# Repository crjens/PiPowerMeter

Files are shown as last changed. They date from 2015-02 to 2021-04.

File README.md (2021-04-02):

PiPowerMeter
=====

PiPowerMeter is an energy usage monitor based on the Cirrus Logic CS5463/5490 energy IC's (http://www.cirrus.com/en/products/pro/detail/P1092.html) and a Raspberry Pi.  It consists of two custom designed stacking pcb's.  The control board houses the power supply, energy IC, voltage sensors and supporting electronics.  The input board houses 16 multiplexed current input channels that allow monitoring up to 16 different circuits via standard clamp-on ct's.  A single control board supports up to 8 stacked input boards for a total monitoring capacity of up to 128 circuits.
The system is controlled by a nodejs based program running on the Raspberry Pi and includes a self contained web based monitoring portal.  Energy data are stored locally on the Raspberry Pi in a sqlite database making the system 100% stand-alone with no requirement for additional hardware or external servers.

Features
--------
 - 100% stand alone system with no reliance on external hardware or servers
 - Ability to monitor up to 128 circuits via round-robin sampling
 - Uses simple off the shelf clamp-on current sensors
 - Highly accurate measurement of voltage, current, power usage and power factor based on CS5463/CS5490 energy IC
 - Raspberry Pi based control system
   * All data stored locally in sqlite database
   * Web based monitoring portal for viewing energy usage and configuration
   * Ability to receive text alerts for overloads or other events.

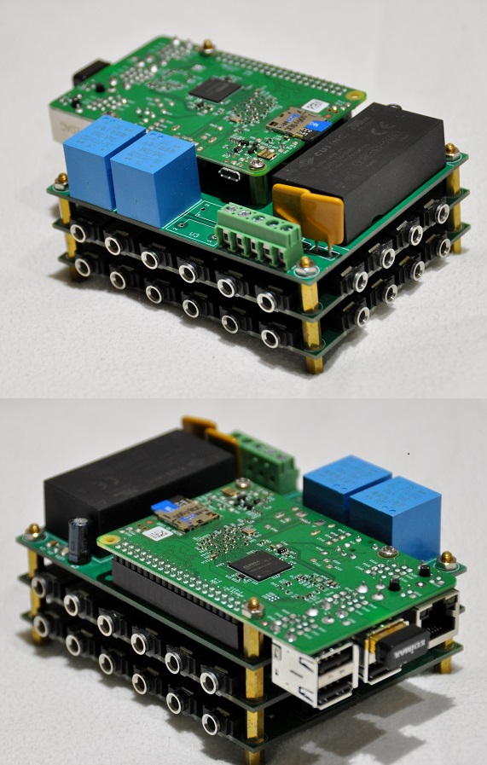
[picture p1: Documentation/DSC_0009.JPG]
hardware
 

Screenshots
-----------
- [Main](https://raw.githubusercontent.com/crjens/PiPowerMeter/master/Documentation/main.png)
- [Daily](https://raw.githubusercontent.com/crjens/PiPowerMeter/master/Documentation/graph.png)
- [Instantaneous](https://raw.githubusercontent.com/crjens/PiPowerMeter/master/Documentation/instant.png)
- [Readings](https://raw.githubusercontent.com/crjens/PiPowerMeter/master/Documentation/readings.png)
- [Configuration](https://raw.githubusercontent.com/crjens/PiPowerMeter/master/Documentation/config.png)

Additional Images
-----------------
- [Installed System](https://raw.githubusercontent.com/crjens/PiPowerMeter/master/Documentation/DSC_0077.JPG)
- [Installed System 2](https://raw.githubusercontent.com/crjens/PiPowerMeter/master/Documentation/DSC_0078.JPG)
- [Sensors](https://raw.githubusercontent.com/crjens/PiPowerMeter/master/Documentation/DSC_0002.JPG)
- [Boards](https://raw.githubusercontent.com/crjens/PiPowerMeter/master/Documentation/DSC_0012.JPG)

Hardware Installation
---------------------
1. The Raspberry Pi mounts directly to the 40-pin header on the control board and is powered from the control board's universal power supply.  Do not attempt to power the Raspberry Pi via its micro usb port or it may be damaged.
2. The control board requires a direct connection to the AC power source that is being monitored.  This AC connection provides both the voltage reference for the energy calculations as well as the power source for the Raspberry Pi and supporting electronics.  The AC power source is connected via 5 pin terminal connector shown [here](https://raw.githubusercontent.com/crjens/PiPowerMeter/master/Documentation/ACIn.jpg) and supports 100-240VAC and 50/60Hz.  

	- For US 120/240V split phase connect Ground, Neutral, AC1 and AC2.
	- For 240V single phase connect Ground, Neutral and AC1.
	- For 3 phase connect Ground, Neutral, AC1, AC2 and AC3.
3. Current sensors are connected to the input board via standard 3.5mm (1/8") audio plugs.  They must be current-type sensors without built-in sense resistors and must produce a full scale output of less than 50mA.  YHDC produces a full line of split-core current sensors that are easy to use, inexpensive and readily available [online](https://www.ebay.com/sch/i.html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). Popular models include:
	- [YHDC-006 (20A)](http://en.yhdc.com/product1311.html?productId=612)
	- [YHDC-013-000 (100A)](http://en.yhdc.com/product1311.html?productId=401)
	- [YHDC-019 (200A)](http://en.yhdc.com/product1311.html?productId=380)
4. Connect the current sensors so that the current polarity reads correctly, (+) for circuits that consume energy and (-) for circuits that produce energy.  Connecting a sensor backwards will not harm anything so if you're not sure which way it should face just pick a direction and then reverse it if the readings are opposite of what you expect. 
	- Current sensors measure the sum of the current passing through them so they should normally be connected to a single conductor.  If connected to a multi-conductor cable, the current flowing in the line and neutral conductors will cancel each other and the sensor will read zero current.
	- YHDC sensors connected to line conductors should be oriented so that the printing on the face of the sensor faces toward the source (there's also an arrow on most sensors that should point toward the source).  If the sensor is connected to the neutral the direction should be reversed.  
5. Once the sensors are installed you'll need to configure the software to enable them.  This is done in the configuration page by adding a new circuit for each sensor and setting the sensor type, board, circuit and voltage reference.
	- There are several preconfigured types for common YHDC sensors and you can add additional types under the configuration tab.  When creating new sensor types set the scale value to 0.05 * the turns ratio of the sensor.  (YHDC SCT-013 has a turns ratio of 2000:1 so scale factor is 0.05*2000=100)
	- Board should be set to the id of the current board that the sensor is plugged into (0-7).
	- Channel should be set to the id that the sensor is plugged into (0-15).
	- Set Voltage to the voltage reference for the circuit.  If you aren't sure you can take a look at the current and voltage waveforms on the circuit page and experiment until you find the voltage reference that most closely matches the phase of the current waveform.
	- SampleTime sets the amount of time in seconds that the input current and voltage are sampled for each calculation.  Decreasing the SampleTime allows faster sampling but may adversly affect the accuracy of the calculations.  Valid values are between 0.05 and 60 seconds.  
	- Incorrect software settings won't cause any damage so you can experiment until you get them right.

Software Installation
---------------------
1. Any of the full size Raspberry Pi models with the 40 pin header are supported including: V1 A+, V1 B+, V2, V3 B, V3 B+ and V4 B.  The additional memory and computing power of the V2/V3/V4 models is recommended.
2. Start with latest Raspbian image from https://www.raspberrypi.org/software/operating-systems/
	1. (verified with Raspberry PI OS Lite 2021-03-04)
	2. It's recommended that you use the Lite version because it's smaller and installs faster but you can use either.
3. login to Pi with Putty or other ssh client
	1. the latest versions of Raspbian have ssh disabled.  You can enable ssh via raspi-config or just create an empty file named 'ssh' in the boot partition of the sd card.
4. Install the PiPowerMeter software by running the following command (you must install with root privileges such as the built-in pi account):
	1. wget -O - https://raw.githubusercontent.com/crjens/PiPowerMeter/master/setup.sh | bash
5. run 'sudo raspi-config' 
	1. set locale and timezone under Localisation options
	2. expand filesystem under Advanced options
	3. change user password (optional)
	4. reboot when prompted after exiting raspi-config
6. Open your browser to http://<Your Raspberry Pi's IP Address>:3000

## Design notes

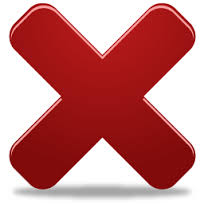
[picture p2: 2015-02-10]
public/images/delete.jpg

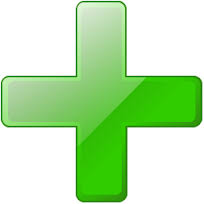
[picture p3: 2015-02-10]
public/images/add.jpg

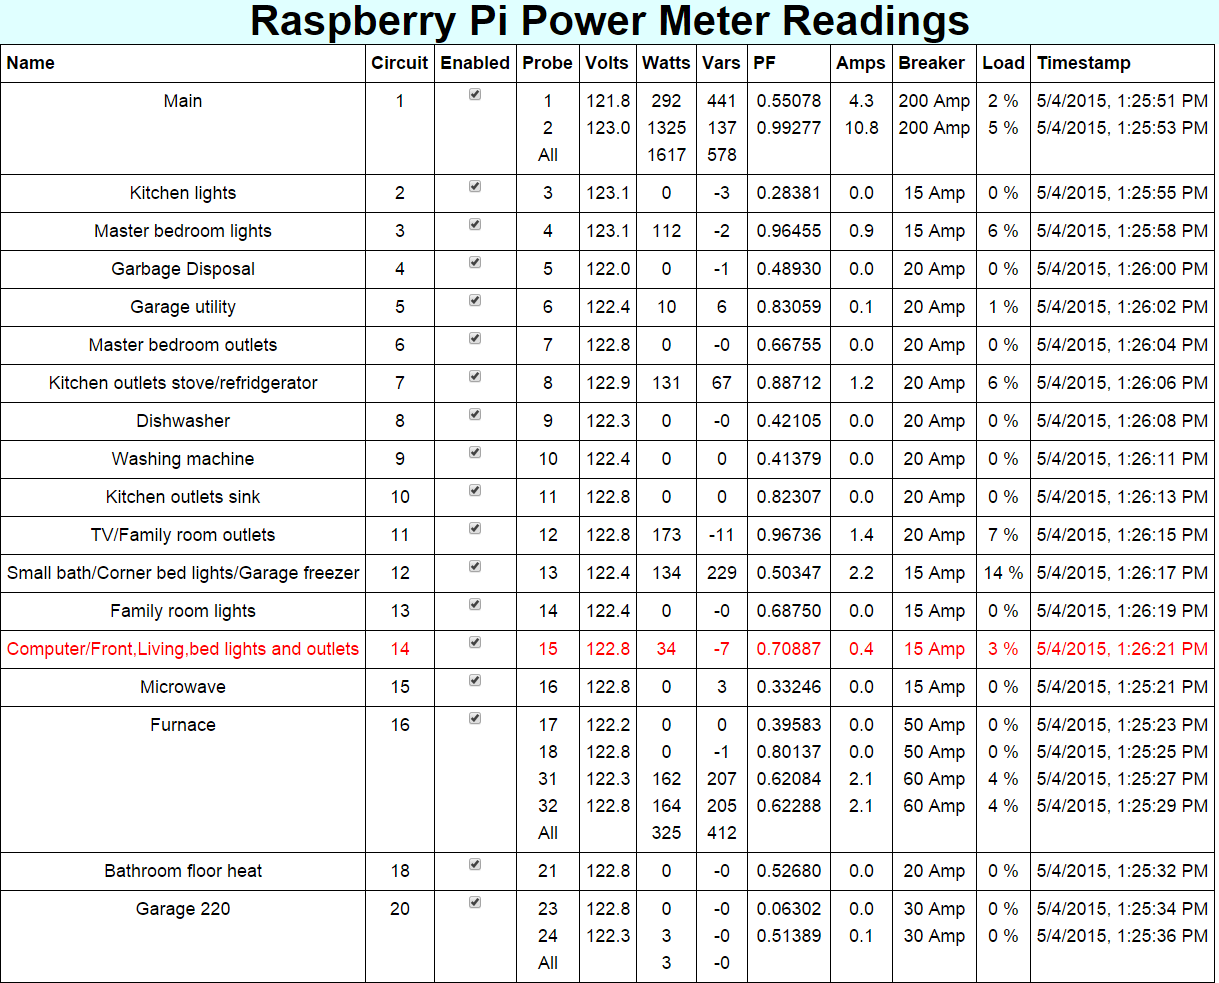
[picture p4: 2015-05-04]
Documentation/readings.png

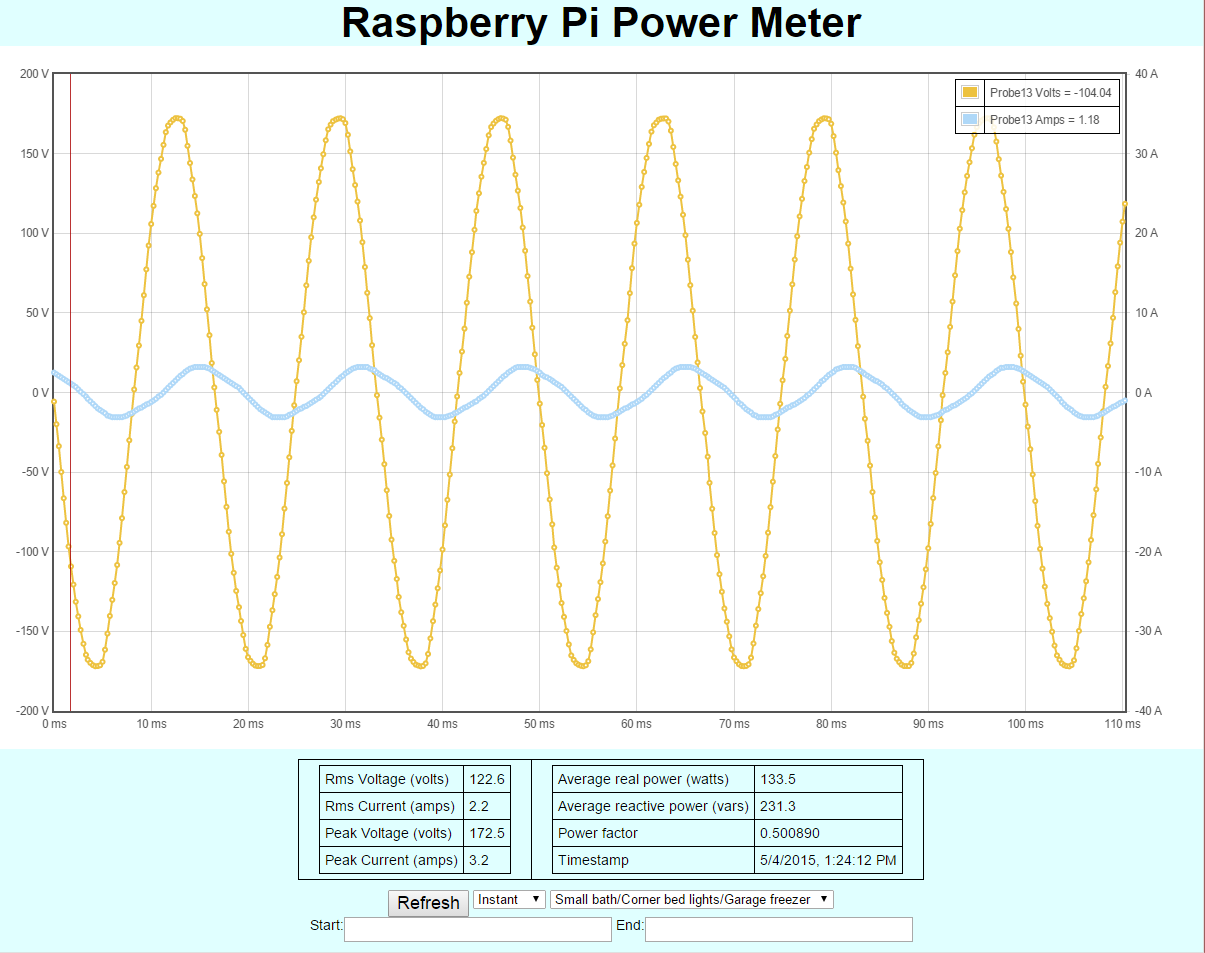
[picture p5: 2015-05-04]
Documentation/instant.png

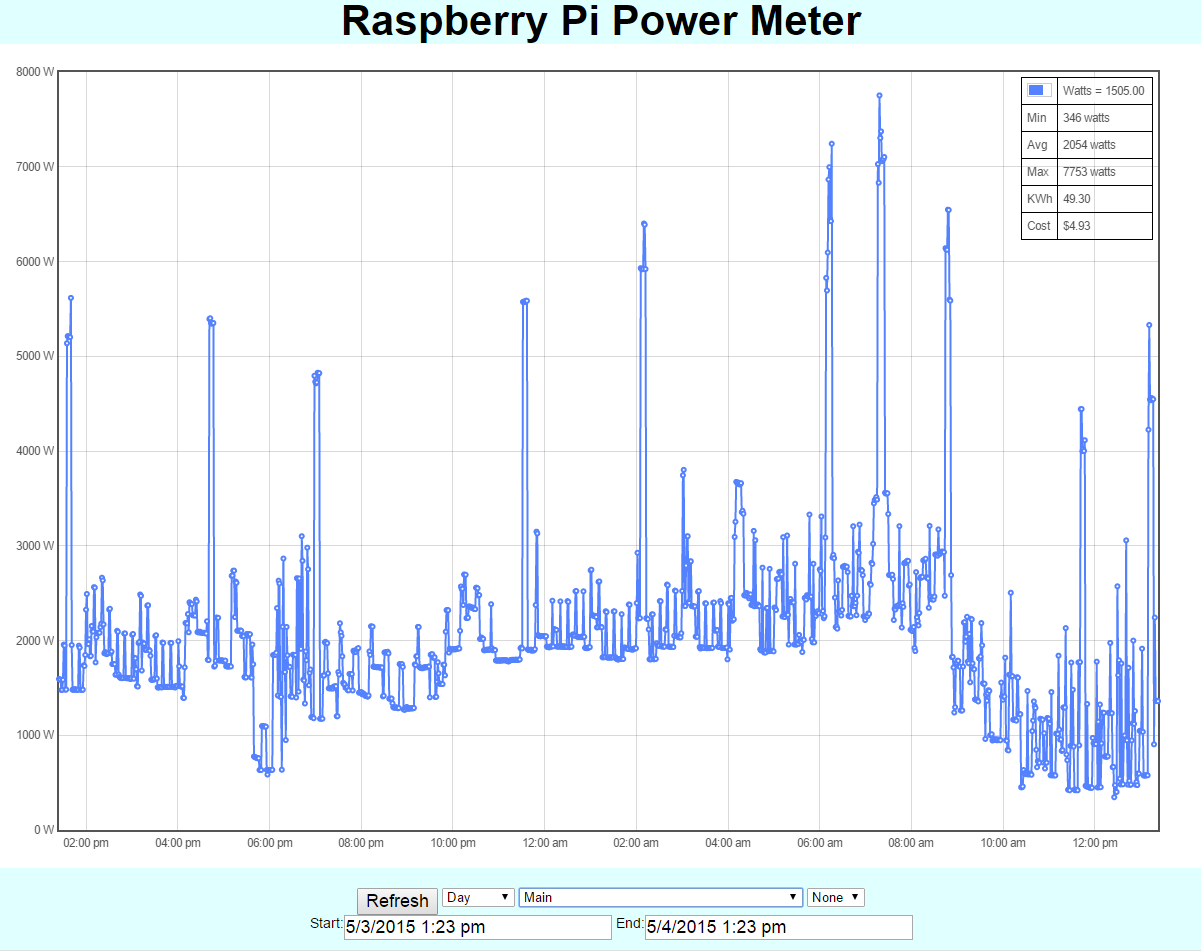
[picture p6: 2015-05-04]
Documentation/graph.png

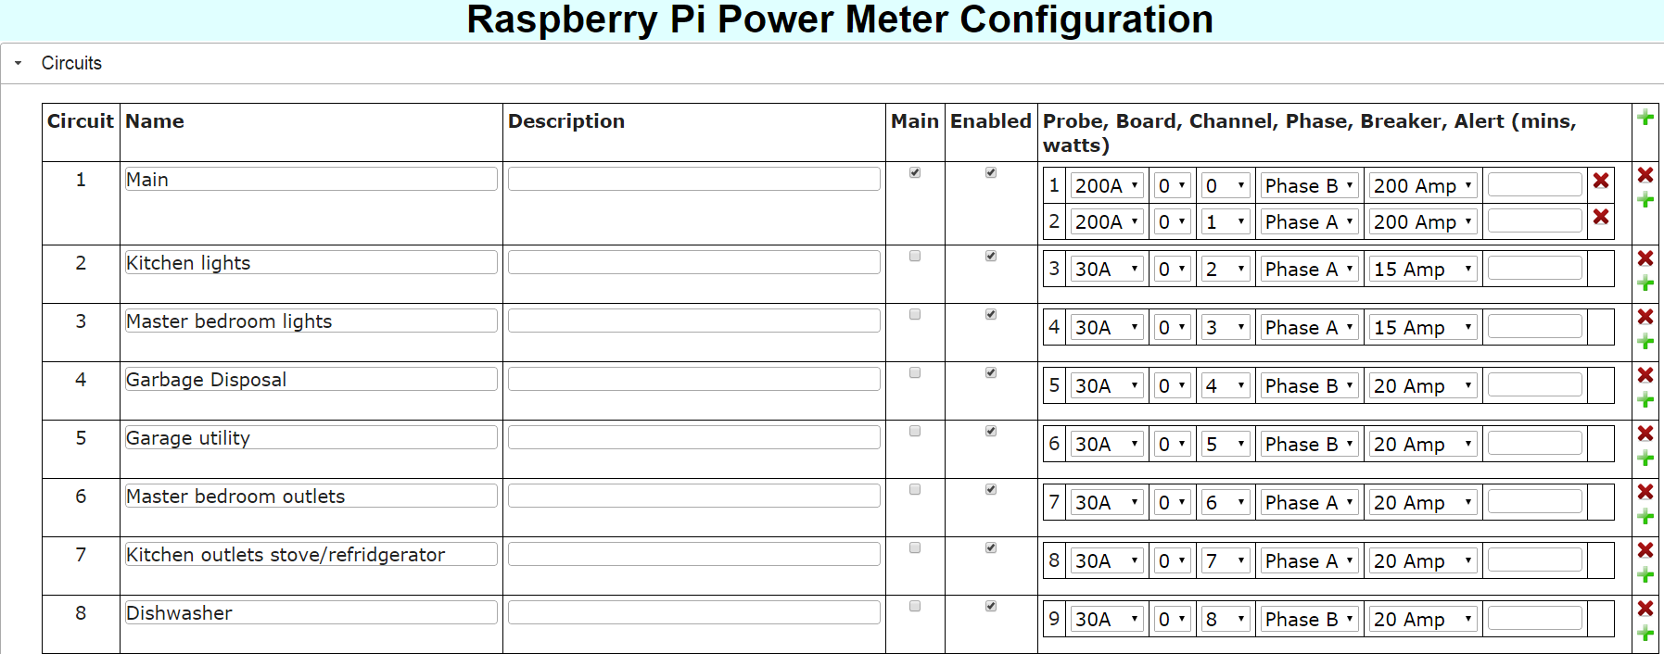
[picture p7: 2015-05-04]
Documentation/config.png

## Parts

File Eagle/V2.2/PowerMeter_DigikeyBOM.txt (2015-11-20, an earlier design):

Qty Value                 Part Num           Package                     Parts                                                   Mfg Name                    VID Vendor Part Num     Description                      Pkg Code           XREF 
6   .1uF                  C1206C104K5RAC7867 C1206                       C1, C2, C4, C6, C10, C14                                Kemet                       DK  399-1249-1-ND       CAP CER 0.1UF 50V 10% X7R 1206   1206               REF2 
1   1.1A 6V               0ZCC0110AF2C       1812                        F1                                                      Bel Fuse Inc                DK  507-1500-1-ND       PTC RESTTBLE 1.10A 16V CHIP 1812 1812               REF24
4   1k                    RC1206FR-071KL     R1206                       R5, R6, R19, R20                                        Yageo                       DK  311-1.00KFRCT-ND    RES SMD 1K OHM 1% 1/4W 1206      1206               REF8 
1   4.096MHz              9B-4.096MBBK-B     HC49/S                      Q1                                                      TXC CORPORATION             DK  887-1876-ND         CRYSTAL                          4.0960MHZ 20PF T/H 1206 
1   10K                   RC1206FR-0710KL    R1206                       R21                                                     Yageo                       DK  311-10.0KFRCT-ND    RES SMD 10K OHM 1% 1/4W 1206     1206               *    
1   10u                   T491C106K016AT     AVX-C                       C3                                                      Kemet                       DK  399-3732-1-ND       CAP TANT 10UF 16V 10% 2413       AVX-C              REF7 
2   22nF                  C1206C223K5RACTU   C1206                       C9, C13                                                 Kemet                       DK  399-1242-1-ND       CAP CER 0.022UF 50V 10% X7R 1206 1206               REF4 
12  59k                   RC1206FR-071KL     R1206                       R7, R8, R9, R10, R11, R12, R13, R14, R15, R16, R17, R18 Yageo                       DK  311-1.00KFRCT-ND    RES SMD 1K OHM 1% 1/4W 1206      1206               REF8 
1   74HC138D              SN74HC138NSR       SO16                        IC1                                                     Texas Instruments           DK  296-12886-1-ND      IC DECODER/DEMUX 3-8 LINE 16SO   16-SOIC            REF21
3   158                   RC1206FR-07158RL   R1206                       R1, R2, R3                                              Yageo                       DK  311-158FRCT-ND      RES SMD 158 OHM 1% 1/4W 1206     1206               *    
4   220pF                 C1206C221J5GACTU   C1206                       C7, C8, C11, C12                                        Kemet                       DK  399-8167-1-ND       CAP CER 220PF 50V 5% NP0 1206    1206               REF3 
1   220uF                 ESH227M016AE3AA    E2,5-6E                     C5                                                      Kemet                       DK  399-6566-ND         CAP ALUM 220UF 16V 20% RADIAL    Radial, Can        REF6 
1   270                   RC1206FR-07270RL   R1206                       R4                                                      Yageo                       DK  311-270FRCT-ND      RES SMD 270 OHM 1% 1/4W 1206     1206               *    
1   4052D                 CD4052BNSR         SO16                        IC2                                                     Texas Instruments           DK  296-14116-1-ND      IC MUX/DEMUX DUAL 4X1 16SO       16-SOIC            *    
1   ACIN                  1935190            SCREWTERMINAL-5MM-5         JP1                                                     Phoenix Contact             DK  277-1580-ND         TERM BLOCK PCB 5POS 5.0MM GREEN  REF36              *    
1   CS5463                CS5463-ISZ         SSOP24                      IC3                                                     Cirrus Logic Inc            DK  598-1096-5-ND       IC ENERGY METERING 1PHASE 24SSOP 24-SSOP            REF23
1   Current Brd Connector PPTC082LFBN-RC     FE08-2                      SV1                                                     Sullins Connector Solutions DK  S7076-ND            CONN HEADER FMAL 16PS .1" DL TIN REF25              *    
3   RSTA 2                RSTA 2             TE5                         F2, F3, F4                                              Bel Fuse Inc.               DK  507-1859-ND FUSE 2A 250/277V RADIAL                  Radial             REF17
1   P6KE6.8A              P6KE6.8A           C1702-15                    D1                                                      Littelfuse Inc              DK  P6KE6.8ALFCT-ND     TVS DIODE 5.8VWM 10.5VC DO204AC  DO-15              REF18
1   RASPI_BOARD_B+_E4     M20-9762046        RASPI_BOARD_B+_EDGES_4DRILL X1                                                      Harwin Inc                  DK  952-1896-ND         20+20 DIL VERT PIN HDR           REF26              *    
3   TV16E                 *                  TV16E                       T1, T2, T3                                              *                           *   *                   *                                *                  *    
1   VSK-S10               VSK-S5-5UA         VSK-S10                     PS1                                                     CUI Inc                     DK  102-2386-ND         CONV AC/DC 5W 5V 1A PCB          *                  REF20
1   green                 LTST-C150GKT       LED_1206                    LED1                                                    Lite-On Inc                 DK  160-1169-1-ND       LED GREEN CLEAR 1206 SMD         1206               REF19

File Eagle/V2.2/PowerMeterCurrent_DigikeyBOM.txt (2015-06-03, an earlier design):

Qty Value              Part Num           Package  Parts                                                                                                 Mfg Name           VID Vendor Part Num Description                      Pkg Code XREF 
1                      SSQ-108-02-T-D     FE08-2   SV1                                                                                                   Samtec Inc         DK  SAM1193-08-ND   CONN RCPT .100" 16POS DUAL TIN   REF33    *    
2   .1uF               C1206C104K5RAC7867 C1206    C1, C2                                                                                                Kemet              DK  399-1249-1-ND   CAP CER 0.1UF 50V 10% X7R 1206   1206     REF2 
16  5                  RC1206FR-075R1L    R1206    R1, R2, R3, R4, R5, R6, R7, R8, R9, R10, R11, R12, R13, R14, R15, R16                                 Yageo              DK  311-5.10FRCT-ND RES SMD 5.1 OHM 1% 1/4W 1206     1206     *    
1   120                RC1206FR-07120RL   R1206    R17                                                                                                   Yageo              DK  311-120FRCT-ND  RES SMD 120 OHM 1% 1/4W 1206     1206     REF12
1   4067D              74HC4067D,652      SO24W    IC1                                                                                                   NXP Semiconductors DK  568-2698-5-ND   IC MUX/DEMUX 1X16 24SOIC         REF31    *    
1   4514D              74HC4514D,652      SO24W    IC2                                                                                                   NXP Semiconductors DK  568-2703-5-ND   IC 4-16 LINE DECOD/DEMUX 24-SOIC REF29    *    
1   Board ID           67996-416HLF       JP8Q     JP1                                                                                                   FCI                DK  609-3220-ND     CONN HEADER 16POS .100 STR TIN   REF30    *    
4   MOUNT-PAD-ROUND3.2 *                  3,2-PAD  H1, H2, H3, H4                                                                                        *                  *   *               *                                *        *    
16  STEREOJACK         SJ1-3525N          STX3100  X1, X2, X3, X4, X5, X6, X7, X8, X9, X10, X11, X12, X13, X14, X15, X16                                 CUI Inc            DK  CP1-3525N-ND    CONN JACK STEREO R/A 5PIN 3.5MM  REF32    *    
16  green              LTST-C150GKT       LED_1206 LED1, LED2, LED3, LED4, LED5, LED6, LED7, LED8, LED9, LED10, LED11, LED12, LED13, LED14, LED15, LED16 Lite-On Inc        DK  160-1169-1-ND   LED GREEN CLEAR 1206 SMD         1206     REF18

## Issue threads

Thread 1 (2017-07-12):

Current Sensors, Config Elements, and Sensor Coverage.

akkord64, 2017-07-12:
I have the dl-ct08cl5 CT's (2000/1) and am unable to configure the readings properly. I also dont seem to understand the scaling factors or where the phase configurations are defined (V1,V2, V3, V1+V2). The CT's seem to be detect voltage and frequency, but no current. I am measuring ~150ohm across the CT's leads before connecting to anything. I am measuring ~44 vac and ~7.6M ohm on a 1AMP load.

Also - For any 220V circuits, do we need both legs? Just curious how the off the shelf clamp meters are calculating load when using only a single leg?

craigjensen, 2017-07-12:
The CS5463 chip outputs voltage and current readings as a number in the range [0-1] which is then multiplied by the voltage and current scale factors to arrive at the actual voltage and current readings.  The scale factors depend on various characteristics of the measurement circuits and the turns ratio of the transformer.  I haven’t used the dl-ct08cl5 CT’s you reference but since they have a 2000/1 turns ratio (same as the YHDC sct-013 100A), you should start with a scale factor of 100 and fine tune as needed.

When you configure your circuits you’ll need to make sure you select the correct voltage reference (V1 or V2) or else you won’t get accurate results.  Take a look at the waveform chart and you’ll be able to see pretty quickly if the voltage and current waveforms are in phase.  If not, just change the voltage reference and check it again.  Also, make sure the CT is installed correctly or else you’ll get negative results.

There are two ways to measure 240V circuits.  If the circuit doesn’t have a neutral the current on each leg must be equal so you can use a single CT on one of the legs and set the voltage reference to V1+V2.  If the circuit has a neutral you’ll get more accurate results by using a CT on each leg with the voltage reference set to V1 for one leg and V2 for the other.

akkord64, 2017-07-19:
Thanks for the reply. Let me try a few things based on your response and post an update. Also I have the power unit currently powered by 120v instead of 220v which *may* be influencing the readings? I will change that and continue with my tuning.

craigjensen, 2017-07-19:
The power supply is designed to work with either 120V or 240V so that shouldn’t influence the results

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

akkord64, 2018-02-10:
Well after having my 4th child I am back to trying to get this project working again. I seem to have hit a wall on this as I cannot get any sensible readings from my unit.

I am not testing with a SCT-019 and was trying to measure a single lef of mains. I have a burden resistor on the probe @26 Ohms (calculated @200amps here: http://tyler.anairo.com/projects/open-energy-monitor-calculator) and had to scale the voltage (366) and current (26) to get a waveform that looks like this (what is the current wave doing??)

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

After a couple of days of frustration with trying to get this to make sense of this (as well as moving between ports, burden resistors, additional boards, Pi's) I decided to unplug all sensors and I am seeing readings (when running server.js directly) of

pi@PowerPi:~/app$ node server.js
next rollup in: 19056531
spawned reader with pid: 2755
2018-02-10T15:42:23.558Z loading configuration...
2018-02-10T15:42:23.560Z waiting for table: Circuits
2018-02-10T15:42:23.561Z waiting for table: Config
2018-02-10T15:42:23.568Z opened database: powermeter.db
2018-02-10T15:42:23.593Z currentSha: c67445f87196163bc68588797bb8e7412fd9d357
2018-02-10T15:42:23.594Z currentDate: 2017-12-14T04:19:55.000Z
2018-02-10T15:42:23.614Z elapsed 0.042 (PRAGMA foreign_keys=on)
2018-02-10T15:42:23.614Z elapsed 0.043 (create table if not exists Probes ( id INTEGER primary key, Type text, Board int check(Board>=0 and Board<=7), CurrentChannel int check(CurrentChannel>=0 and CurrentChannel<=15), VoltageChannel int check(VoltageChannel>=0 and VoltageChannel<=3), Breaker int, Alert Text, SourceType int);)
2018-02-10T15:42:23.617Z elapsed 0.045 (create table if not exists Config ( Name text primary key, Value Text);)
2018-02-10T15:42:23.618Z Config table ready
2018-02-10T15:42:23.619Z elapsed 0.048 (create table if not exists Circuits ( id INTEGER primary key, Name Text, Description Text, Enabled int, IsMain int, Probes text);)
2018-02-10T15:42:23.620Z Circuits table ready
2018-02-10T15:42:23.623Z elapsed 0.007 (pragma table_info(Probes);)
2018-02-10T15:42:23.625Z Probes table ready
2018-02-10T15:42:23.625Z elapsed 0.008 (Insert or ignore into Config Values('Port', '3000');)
2018-02-10T15:42:23.626Z elapsed 0.008 (Insert or ignore into Config Values('DeviceName', '');)
2018-02-10T15:42:23.626Z elapsed 0.008 (Insert or ignore into Config Values('Price', '0.1');)
2018-02-10T15:42:23.626Z elapsed 0.008 (Insert or ignore into Config Values('Region', 'en-US');)
2018-02-10T15:42:23.626Z elapsed 0.008 (Insert or ignore into Config Values('VoltageScale', '384');)
2018-02-10T15:42:23.626Z elapsed 0.008 (Insert or ignore into Config Values('Probes', '[{''Name'':''SCT-006'',''Factor'':''40''},{''Name'':''SCT-010'',''Factor'':''152''},{''Name'':''SCT-013'',''Factor'':''101''},{''Name'':''SCT-016'',''Factor'':''152''},{''Name'':''SCT-019'',''Factor'':''295''}]');)
2018-02-10T15:42:23.627Z elapsed 0.008 (Select * from Config where Name = 'BackupDB';)
2018-02-10T15:42:23.627Z elapsed 0.007 (Insert into Circuits (id, Name, Description, Enabled, IsMain, Probes) select null,'Circuit 1','',1,0,'1' where (select count(*) from Circuits) = 0;)
2018-02-10T15:42:23.628Z elapsed 0.007 (create table if not exists Readings (id INTEGER primary key, CircuitId int, I real, V real, P real, Q real, PF real, Timestamp int, Compacted int, F real, foreign key(CircuitId) references Circuits(id));)
2018-02-10T15:42:23.629Z elapsed 0.011 (Insert or ignore into Config Values('Mode', '000060');)
2018-02-10T15:42:23.629Z elapsed 0.011 (Insert or ignore into Config Values('Config', '001001');)
2018-02-10T15:42:23.631Z elapsed 0.007 (Insert into Probes (id, Type, Board, CurrentChannel, VoltageChannel, Breaker, Alert, SourceType) select 1,'SCT-006',0,0,0,20,null,0  where (select count(*) from Probes) = 0;)
2018-02-10T15:42:23.632Z elapsed 0.004 (pragma table_info(Readings);)
2018-02-10T15:42:23.633Z Readings table ready
2018-02-10T15:42:23.634Z elapsed 0.001 (select count(*) as Rows from Readings;)
2018-02-10T15:42:23.635Z elapsed 0.002 (create index if not exists Readings_Timestamp_CircuitId_P_idx on Readings(Timestamp, CircuitId, P);)
2018-02-10T15:42:23.636Z elapsed 0.003 (create index if not exists Readings_CircuitId_Timestamp_P_idx on Readings(CircuitId, Timestamp, P);)
2018-02-10T15:42:23.666Z elapsed 0.002 (select * from Circuits;)
2018-02-10T15:42:23.668Z elapsed 0.003 (Select * from Config;)
2018-02-10T15:42:23.669Z username:     password:
2018-02-10T15:42:23.670Z Setting port: 3000
2018-02-10T15:42:23.691Z App Server running at port 3000
2018-02-10T15:42:23.691Z elapsed 0.024 (Select * from Probes;)
2018-02-10T15:42:23.695Z elapsed 0 (Select * from Config;)
2018-02-10T15:42:23.696Z read: DeviceName->
2018-02-10T15:42:23.696Z read: Mode->000060
2018-02-10T15:42:23.697Z read: Region->en-US
2018-02-10T15:42:23.697Z read: VoltageScale->384
2018-02-10T15:42:23.697Z read: Port->3000
2018-02-10T15:42:23.697Z read: Price->0.1
2018-02-10T15:42:23.697Z read: Config->001001
2018-02-10T15:42:23.701Z mqtt: undefined
reader closed 1
reader closed 2
Opening device: /dev/spidev0.0 at 2000000 Hz, mode 0, 8 bits, 0 us delay
Device opened with mode: 0, bits: 8, speed: 2000000
Device opened: Hardware version: 2.2
RESET
Register dump:
0 - Config: 001001
1 - CurrentDCOffset: 000000
2 - CurrentGain: 400000
3 - VoltageDCOffset: 000000
4 - VoltageGain: 400000
5 - CycleCount: 000fa0
6 - PulseRateE: 800000
7 - InstCurrent: 0003d0
8 - InstVoltage: 1764ce
9 - InstPower: 000070
10 - RealPower: fffccf
11 - RmsCurrent: 002c2e
12 - RmsVoltage: 570aa6
13 - Epsilon: 01eb85
14 - PowerOffset: 000000
15 - Status: 900085
16 - CurrentACOffset: 000000
17 - VoltageACOffset: 000000
18 - Mode: 000060
19 - Temp: 18fc00
20 - AveReactivePower: 000598
21 - InstReactivePower: 000004
22 - PeakCurrent: ffc40e
23 - PeakVoltge: c5446a
24 - ReactivePowerTriangle: 0006cb
25 - PowerFactor: c9970a
26 - InterruptMask: 800000
27 - ApparentPower: 000782
28 - Control: 000000
29 - HarmonicActivePower: ffffeb
30 - FundamentalActivePower: fffce4
31 - FundamentalReactivePower: 0005a8
2018-02-10T15:42:23.987Z latest software version: c67445f87196163bc68588797bb8e7412fd9d357
2018-02-10T15:42:23.987Z software is up to date - will periodically check for updates
2018-02-10T15:42:24.400Z start: GET /config?_=1518277345681
2018-02-10T15:42:24.406Z sending cached config
write: init serial port(FFFFFFFE)
command: reset(80)
2018-02-10T15:42:24.422Z end: GET /config?_=1518277345681 22 ms
status: 800005
write: clear status(5EFFFFFF)
read: read Mode register(24FFFFFF) -> 000000
write: hpf on with current phase compensation(64000060)
read: read Mode register(24FFFFFF) -> 000060
read: read configuration register(00FFFFFF) -> 000001
write: interrupts set to high to low pulse with phase comp(40001001)
read: read configuration register(00FFFFFF) -> 001001
epsilon before: 0.01250004768371582
write: set epsilon to 01eb85(5A01eb85)
epsilon after: 0.014999985694885254
initialized
setting isr pin to: 5, upDn: 2, edge: 1
2018-02-10T15:42:24.496Z start: GET /waveform?circuitId=1&_=1518277345682
2018-02-10T15:42:24.497Z waveform(1)
2018-02-10T15:42:24.502Z end: GET /waveform?circuitId=1&_=1518277345682 6 ms
2018-02-10T15:42:27.285Z Circuit 1 : V= 130.6  I= 0.0  P= -1.5  Q= -1.5  PF= -0.4082  F= 60.013  F2= 60.000 (500 samples in 124.705339ms)
2018-02-10T15:42:27.313Z elapsed 0.023 (select round(min(P),0) as min, round(max(P),0) as max, round(avg(P),0) as avg from readings where CircuitId = 1 and Timestamp >= 1518190947.287 and Timestamp < 1518277347.287;)
2018-02-10T15:42:27.314Z setting lastkwh for ckt: 1 to -0.024
2018-02-10T15:42:29.861Z start: GET /config?_=1518277351149
2018-02-10T15:42:29.863Z sending cached config
2018-02-10T15:42:29.866Z end: GET /config?_=1518277351149 5 ms
2018-02-10T15:42:29.949Z start: GET /waveform?circuitId=1&_=1518277351150
2018-02-10T15:42:29.950Z waveform(1)
2018-02-10T15:42:29.966Z end: GET /waveform?circuitId=1&_=1518277351150 17 ms
2018-02-10T15:42:30.079Z Circuit 1 : V= 130.6  I= 0.0  P= -1.5  Q= 2.7  PF= -0.4269  F= 60.004  F2= 60.000 (500 samples in 124.714608ms)
2018-02-10T15:42:30.263Z start: GET /favicon.ico
2018-02-10T15:42:30.279Z end: GET /favicon.ico 16 ms
2018-02-10T15:42:32.859Z Circuit 1 : V= 130.6  I= 0.0  P= -1.5  Q= 2.7  PF= -0.4282  F= 60.003  F2= 60.000 (500 samples in 124.728442ms)
2018-02-10T15:42:35.639Z Circuit 1 : V= 130.6  I= 0.0  P= -1.5  Q= 2.6  PF= -0.4285  F= 59.999  F2= 60.000 (500 samples in 124.72094ms)
2018-02-10T15:42:38.457Z Circuit 1 : V= 130.6  I= 0.0  P= -1.5  Q= 2.6  PF= -0.4277  F= 60.011  F2= 60.000 (500 samples in 125.451381ms)
2018-02-10T15:42:41.239Z Circuit 1 : V= 130.5  I= 0.0  P= -1.5  Q= 2.6  PF= -0.4246  F= 59.997  F2= 60.000 (500 samples in 124.714629ms)
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
craigjensen, 2018-02-10:
Hi Chris,

I have tested the SCT-019 sensors and they work well but the PiPowerMeter boards have built-in sense resistors so you should not be adding your own.  I’ve seen some pretty unusual current waveforms especially if you have lots of electronics connected that might account for what you are seeing. Please try removing any additional burden resistors and connect the current probes directly to the current board.  That should give you a more sensible reading.

The voltage waveform is read directly from the connected power source.  The current sensors only read current, not voltage, which is why you still see a voltage waveform when not current sensors are connected.

Let me know if you are still having issues and I’ll help however I can.

Craig

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

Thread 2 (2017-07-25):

Potential issue with your current sense resistors

High5Apps, 2017-07-25:
Hey Craig,

First off, thanks for open sourcing this project! I've recently been using it as a reference to develop a power monitor with 6 CS5463s for 3 phases of solar generation and 3 phases of household consumption.

Unfortunately, I think that I may have found a potential issue when examining your hardware specs. In your [PowerMeterCurrent_DigikeyBOM.txt](https://github.com/crjens/PiPowerMeter/blob/master/Eagle/V2.2/PowerMeterCurrent_DigikeyBOM.txt) it indicates that the value of your current sensing resistors is 5 ohms. In your documentation you recommend using [sct-013-000 100A:50mA](https://raw.githubusercontent.com/crjens/PiPowerMeter/master/Documentation/DSC_0002.JPG) current transducers. Furthermore, on page 7 of the [CS5463 datasheet](http://www.mouser.com/ds/2/76/cs5463_f3-48303.pdf), it indicates that the differential current inputs can handle up to a 500mVpp difference (+/- 250mV since the signals are ground tied).

From those numbers I'm getting that the CS5463 would only be able to measure up to a maximum of 70.8A of sinusoidal input, not 100A before the CS5463 current readings start "peaking". I believe that you may have forgotten to divide by sqrt(2) when choosing your 5 ohm current sense resistor. My reasoning for dividing by sqrt(2) when going from a peak-peak to RMS can be found at the bottom of the [Average Electrical Power section of the Root Mean Square](https://en.wikipedia.org/wiki/Root_mean_square#Average_electrical_power) Wikipedia page where it states that Vrms = Vp / sqrt(2).

If the CS5463 can measure a max of 250mV peak, then it can only handle a 250mVp / sqrt(2) = 177mVrms sinusoidal signal without "peaking". Dividing this by your current sense resistor of 5 ohms gives 177mVrms / 5 ohms = 35.4 mArms through your current sense resistor. Finally, multiplying that by the turns ratio for the sct-013-000 of 100A:50mA (N = 2000) gives 35.4mArms * 2000 = 70.8Arms through the current transducer before "peaking" begins to occur.

I believe that if you were to substitute a 5.00 ohm / sqrt(2) = 3.5 ohm resistor, you would again be able to read the full 100Arms range of the sct-013-000.

I am quite new to hardware of this complexity, so it is likely that I have made a mistake in dividing by sqrt(2), but I wanted to bring this to your attention nonetheless. Have you been able to take measurements above 70.8 A of sinusoidal current? While currents this high are unlikely to be seen under normal circumstances, I believe that the PiPowerMeter would not be able to handle them.

Thanks again for your time and for developing this amazing project,
Julian

craigjensen, 2017-07-26:
Your calculations look correct for the sense resistor alone but they don't account for the influence of other components such as the multiplexers and filters in the circuit.  During prototyping I experimented with different values of the sense resistor until arrived at a value that closely matched the full scale reading of the sct-013 with that of the cs5463 and it turned out to be around 5 ohms.  If you look at the software scale factor used for the sct-013 sensor you'll see that it defaults to 101 which means that when the cs5463 outputs a full scale current reading (Irms = 1.0) the resulting current reading will be 101A.  That said, 3.5 ohms would have worked just as well and provided a little more headroom to measure higher current levels.  I'm sorry I don't have a more scientific analysis on how I arrived at the value of 5 ohms but sometimes a little trial and error works as well as anything :)

I'm glad you found my project informative and I'd love to see more details on what you are building if you are willing to share.

High5Apps, 2017-07-27:
Oh you're right- I definitely forgot to include the other resistances in my calculations. Since I have 6 CS5463s for 6 inputs, I don't have any multiplexers on that path, but I'll definitely need to account for the current sense filters.

As far as the project goes, I've been working on developing a python/Raspberry Pi-based energy monitor on-and-off for the past year or so. Previously, I had just been using an ADC to sample 4 sct-013-030 current sensors (3 phases of consumption 1 phase of generation), and then multiplying the values by the "expected" voltage (230V here). But a few months ago I decided I wanted to start taking voltage into account. I also wanted the option to go up to 3 phases of generation. During my research I found your project and learned about CS5463s for the first time. My requirements differ from yours in 2 main ways. First, I only need to measure 6 inputs, not 128 (although I think the stackable boards are a really neat idea). Second, I didn't want to do the round-robin sampling, but since I'm only doing 6 inputs and the CS5463s are relatively cheap, I just incorporated 6 of them. I'm planning to develop a machine learning energy disaggregation system to remove the need for more than 6 inputs.

My first prototype board (with 5 ohm current sense resistors) is supposed to arrive tomorrow, so I'll finally be able to experimentally test out the scales. If you don't mind, do you remember what your experimental setup was for finding the voltage and current scales? I imagine it would be something like this:
- Power the Raspberry Pi using the micro USB cable instead of through the PSU
- Attach a function generator to the screw terminals, producing a known current and voltage at 50 (or 60) Hz
- Place the sct-013-000 around the positive cable of the function generator
- Read at least 1 computational cycle of RMS voltage and current through the CS5463,
- Divide the expected rms voltage or current by the measured values on the scale [-1, 1)

Am I missing anything? Thanks again for your help.

craigjensen, 2017-07-27:
That's pretty much the way I did it - attach known voltage and current and adjust scale factors to match.  I'm not sure if you are interested in reading the instantaneous V/I values but one thing to look out for is that the Raspberry Pi may have problems reading those values from 6 CS5463's at the same time.  It may work but that's a lot of interrupts to process...  If you limit to only reading the values at the end of the computation cycle you should have no issues.

If you haven't already, you might want to take a look at the CS5464 and CS5467 IC's.  They are able to measure multiple channels and may reduce the number of chips you need to use.

High5Apps, 2017-07-27:
Great thanks, I just wanted to make sure I wasn't off base with that setup.

I opted away from interrupts in my design because I was worried about that as well. To reduce complexity, I've just muxed the 6 chip selects and I'm planning to poll the status registers to see when a new conversion cycle measurement is ready.

I looked into the CS5463 and 67 when I first learned about the Cirrus website, but if I remember correctly, I don't think that those 2 chips really add extra inputs. It seemed like they just added redundancy to the single-phase measurement for tamper-protection. While tamper protection isn't a priority for me, I did briefly look into the ADE7878, which someone mentioned on one of your forum posts. Unfortunately, its complexity was a little too intense for my EE skills, but I believe it truly does take 3 phases of input as well as performing tamper protection.

One further question- did you have to do any phase compensation? If so what was your setup for experimentally determining it? Again, thanks a lot!

craigjensen, 2017-07-27:
I have experimented with phase compensation to account for the non-linearity in the CT's.  If you look [here](https://learn.openenergymonitor.org/electricity-monitoring/ct-sensors/yhdc-ct-sensor-report) you'll see a graph that indicates the SCT-013 has a phase shift of ~4 degrees for a 22ohm shunt resistor.  Another approach I took was to hook up a purely resistive load and then adjust until the reported power factor was as close to 1.0 as I could get.  Neither of these is likely going to be 100% accurate and if you need super accurate results you'll probably want to look into using [Rogowski coils](https://en.wikipedia.org/wiki/Rogowski_coil) instead of CT's to measure current.

High5Apps, 2017-08-17:
Sorry for the delayed response, I haven't had as much time to work on this recently as I'd hoped.

I have finally been able to experimentally test the voltage and current scales for my prototype board.
My concerns about the 3.5 Ohm vs 5 Ohm burden resistors were unfounded, and so I am closing this issue.

Using known RMS currents and voltages, I determined that the current scales for my 6 inputs were between 102A and 105A, which should allow full scale current measurements over the SCT-013-000's linear range. My voltage scales were between 357V and 360V, which also allows for full scale voltage measurements. These results are consistent with your scales (101A, 384V), given that my design was somewhat modified from yours.

I was also able to do phase compensation for the SCT-013-000s using large resistive loads, achieving power factors of between 0.99990 and 0.99999.

I've still got more work to do, but I'm eventually hoping to open source my CS5463 python library too.

Thanks again for your help and for sharing your project with all of us!

Closed 2017-08-17.

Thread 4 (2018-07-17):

Interested for electric motorcycles

biva, 2018-07-17:
Hello,

We are a young company starting an electric motorcycle business in Uganda. For this purpose, we need to measure the consumption of 6 motorcycles chargers independently. And your solution looks terrific. Is there a way to find the hardware you use here? We are open to discussion to buy your solution.

Hope to read you soon!

crjens, 2018-07-19:
I do have boards available.  Please contact me directly at crjens _at_ hotmail.com for details.  Thanks!

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

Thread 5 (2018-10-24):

Components

xomanuel, 2018-10-24:
Hi  Craig!

I'm XO from the Philippines. First, I would like to thank you for your PiPowerMeter. I recently used your schematic of the board and have it printed. I bought the BOM, however some are not available, will it be possible to change the components with the same specifications? Also, my mains do not have grounding and neutral wire, it is ok to use only the two live wire? (240V Line-Line).

Thanks!

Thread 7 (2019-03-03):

Resistor array on back of board

jdeglavina, 2019-03-03:
First of all. Thanks for all the work that you've done with this project, and for putting it up on here.

I just uploaded a slightly reworked version of the two boards to my fork of your project. I moved everything that was on the bottom side to the top, and replaced through hole components with smd.

I'm just curious if the resistor arrays for the voltage readings were on the back of the board for a reason, like to cut down on transients interfering with other components? I noticed the space between the copper fills was increased a lot around the high voltage components, but wasn't sure if that was enough.

craigjensen, 2019-03-03:
Interesting - I've actually made similar improvements to the boards but haven't uploaded the new designs yet.  My latest boards also have everything on top and I haven't noticed any difference in performance.

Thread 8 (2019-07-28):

Are these board purchaseable someplace?

xekon, 2019-07-28:
Are these board purchaseable someplace?

This looks to be the best raspberry pi based power monitor I could find on the net.

the only other one I could find was this: https://store.ncd.io/product/12-channel-on-board-95-accuracy-ac-current-monitor-with-i2c-interface/

but this project looks more flexible and even has a way to monitor the mains in the breaker panel.

crjens, 2019-07-29:
I have boards available.  Please DM me at crjens@hotmail.com<mailto:crjens@hotmail.com> for details

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

presslab-us, 2020-03-17:
Are these still available?  I'm not sure if the email listed is still valid.  I sent an email 5 days ago but have yet to get a reply.

crjens, 2020-03-17:
Yes – I do have boards available.  Sorry if I missed your previous  mail.  It may have gone into my junk folder and I missed it.  Please email again at crjens @ hotmail.com<mailto:crjens@hotmail.com> and I’ll send details.

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

rogerfar, 2021-04-12:
@crjens do you still have some boards?

crjens, 2021-04-13:
Hi Roger,

I do have boards available for purchase.  The control board is $75 and each 16 channel input board is $25.  Shipping is $10 in the US or $20 outside the US.  The boards come fully assembled and tested.  You'll need to supply your own Raspberry Pi and current sensors.

If you are interested in purchasing, please contact me directly at ***@***.******@***.***> and I'll send payment details.

Thanks,
Craig

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

fxstein, 2021-07-13:
Sent you an email. Thanks!

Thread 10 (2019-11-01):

How 's the kWh calculation going?

gelezayka, 2019-11-01:
How 's the kWh calculation going?

How many measurements take place per hour?

And in general it is interesting for how much ms get full data on current?

Just I made an almost similar device, but I use MCP3208CI/SL there and all rms calculate in code, more than 40 current sensors do not get to use to withstand 3200 measurements per hour.

Thanks.

crjens, 2019-11-01:
Power calculations are performed by the CS5463/5490 IC's.  By default the chip samples the incoming current and voltage waveforms for 1 second (at a rate of 4000 samples/sec) and then does the power calculations.  It can be configured to use fewer total samples at the expense of potentially reduced accuracy.  Details on the chips are here: [CS5463](https://statics.cirrus.com/pubs/proDatasheet/CS5463_F3.pdf), [CS5490](https://statics.cirrus.com/pubs/proDatasheet/CS5490_F3.pdf)

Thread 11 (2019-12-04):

MQTT Provision

xianrecords2015, 2019-12-04:
Hello,

Thanks for making this project. I started my own with a standard MCP3208 but found that a 12bit ADC is not accurate enough. I like the approach of the CS5490.

I have a question for you. In the driver.js, I saw that you have some provision for MQTT but I could not find anywhere on the configuration web page a way to enter the MQTT server, username, password and port. Am I missing something ?

Thanks

Chris

crjens, 2019-12-04:
It’s not exposed by default.    Add ‘?advanced=1’ to the url and you should see it

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

xianrecords2015, 2019-12-04:
Thank you for your answer,

I was trying to analyze the CS5490.js and forgive my ignorance and little knowledge of Javascript but you are requiring a CS5490 at the beginning of the code. I am assuming that this is not the CS5490.js file itself. There are a number of call to a cs5490 library (ie: cs5490.DigitalRead) that I cannot reference. Where are they coming from ?

Also you have define 4 input pins to read the HW version. I have a hard time to find them on the schematics. I can find the output pins but I am not understanding the inputs.

Thanks

Christian

xianrecords2015, 2019-12-04:
I now understand the 4 input pins for HW version.

I also see that you have developed a CS5490 C++ in one of the other branch that I believe is what you require in the cs5490.js. I am wondering in the setup file how you import it in the project and the setup

crjens, 2019-12-05:
The 4 input pins are to determine the hardware version of the boards.  There are drivers written in C for both the CS5463 and CS5490 chips.  They use nan<https://github.com/nodejs/nan> to interface with the node based PiPowerMeter software.

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

xianrecords2015, 2019-12-11:
There seems to be some inconsistencies in the V4 Schematics/Board.

- Are the shunt resistance R1-R16 5.1Ohms or 7.5Ohms ? They are listed 5 Ohms in the schematics yet they call a 7.5Ohms Digikey Part number in the info

- the PJ313D have the CP1-3525N-ND Digikey Part number in V2 BOM (There is no V4 BOM). These seems to be thruholes connectors. But the board is setup for surface mount connector. Do you have the reference of these SMT connectors ?

Tx

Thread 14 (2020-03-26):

i2c conflict

asquelt, 2020-03-26:
is it possible to rewire GPIO2 and GPIO3 (pin 3 and 5) to some other pins?
i'd like to use i2c along with pi power meter, but not sure about pullup resistors or other hardware limitations.

i'm connecting it on ribbon, so it's easy to me to rewire and change the reader code accordingly.

asquelt, 2020-04-07:
nevermind, i've found another unocuppied i2c-0 bus on pins 27 & 28 which are apparently reserved and not used by pi power meter.

done that according to this howto: https://learn.sparkfun.com/tutorials/raspberry-pi-spi-and-i2c-tutorial/all
and it works.

Closed 2020-04-07.

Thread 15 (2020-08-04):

Resistor Values vs Part Numbers in BoM

alisarwar, 2020-08-04:
The BoM file generated by eagle for V4.0 boards has a discrepancy.

On PiPowermeter board. The resistors value is 59K. The BoM Partnumber is of 1K resistors

On PiPowermeterCurrent board. The resistor value is 5K but the part number is 7.5K.

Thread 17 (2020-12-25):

Voltage reference not working

elektrolubach, 2020-12-25:
Hi folks,

I am using the boards of the fork from [CircuitSetup](https://github.com/CircuitSetup/PiPowerMeter) which are based on the Version 2.2 of the [crjens](https://github.com/crjens/PiPowerMeter/tree/master/Eagle/V2.2) boards. Due to circumstances I was only able to finish the assembly of the boards by now and I am trying to use the current software of this [master version](https://github.com/crjens/PiPowerMeter).

I have troubles getting the voltage reference working. The probe overview looks like this:
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

The configuration of the probes is this:
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

The overall configuration is this:
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

For reference, here some information:
I am living in Germany and trying to use a three phase network with neutral.
I am using the TV16E voltage transformers from YHDC (black ones).

What seems strange to me:
The frequency of all three phase-phase references is nearly a plausible value of ~50Hz.

Can anybody give me a hint on this, where to look first?
Is there any configuration that has to be done additionally to the this to work (e.g. enable voltage references or something like that)?
How can I check if the CS5463 is reading a plausible voltage value?

Thanks!
Cheers elektrolubach

elektrolubach, 2020-12-29:
I headed forward and looked for the log files the software writes:
`2020-12-29T22:40:32.338Z C3 - V3-N : V= 0.0  I= 0.0  P= 0.0  Q= 0.0  PF= 0.0000  F= 0.000  F2= 56.224 (500 samples in 81.281582ms)
2020-12-29T22:40:33.311Z C1 - V1-N : V= 0.1  I= 0.0  P= 0.0  Q= 0.0  PF= 0.0000  F= 0.000  F2= 56.224 (500 samples in 82.943984ms)
2020-12-29T22:40:34.280Z C2 - V2-N : V= 0.1  I= 0.0  P= 0.0  Q= 0.0  PF= 0.0000  F= 0.000  F2= 56.224 (500 samples in 72.120814ms)
2020-12-29T22:40:35.245Z C3 - V3-N : V= 0.0  I= 0.0  P= 0.0  Q= 0.0  PF= 0.0000  F= 0.000  F2= 56.224 (500 samples in 76.385414ms)
2020-12-29T22:40:36.218Z C1 - V1-N : V= 0.1  I= 0.0  P= 0.0  Q= 0.0  PF= 0.0000  F= 0.000  F2= 56.224 (500 samples in 83.478568ms)`

These are five example lines from the output...

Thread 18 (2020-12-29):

Software installation errors

Jendemen, 2020-12-29:
Hi,
Just before I wanted to order the components I try to install the software, but whatever I try, I keep getting errors as below.

Does anyone has suggestions? I am running 2020-02-13-raspbian-buster-lite

Many thanks in advance, Jan

make: *** [CS5490.target.mk:109: Release/obj.target/CS5490/CS5490.o] Error 1
make: Leaving directory '/home/pi/app/node_modules/CS5490/build'
gyp ERR! build error
gyp ERR! stack Error: `make` failed with exit code: 2
gyp ERR! stack     at ChildProcess.onExit (/home/pi/.nvm/versions/node/v14.15.3/lib/node_modules/npm/node_modules/node-gyp/lib/build.js:194:23)
gyp ERR! stack     at ChildProcess.emit (events.js:315:20)
gyp ERR! stack     at Process.ChildProcess._handle.onexit (internal/child_process.js:277:12)
gyp ERR! System Linux 4.19.97-v7+
gyp ERR! command "/home/pi/.nvm/versions/node/v14.15.3/bin/node" "/home/pi/.nvm/versions/node/v14.15.3/lib/node_modules/npm/node_modules/node-gyp/bin/node-gyp.js" "rebuild"
gyp ERR! cwd /home/pi/app/node_modules/CS5490
gyp ERR! node -v v14.15.3
gyp ERR! node-gyp -v v5.1.0
gyp ERR! not ok
>>> Enable UART
>>> Disable bluetooth
Removed /etc/systemd/system/multi-user.target.wants/hciuart.service.
>>> CS5490 is installed.  Please reboot to apply changes.

> sqlite3@5.0.0 install /home/pi/app/node_modules/sqlite3
> node-pre-gyp install --fallback-to-build

node-pre-gyp WARN Using request for node-pre-gyp https download
node-pre-gyp WARN Tried to download(403): https://mapbox-node-binary.s3.amazonaws.com/sqlite3/v5.0.0/napi-v3-linux-arm.tar.gz
node-pre-gyp WARN Pre-built binaries not found for sqlite3@5.0.0 and node@14.15.3 (node-v83 ABI, glibc) (falling back to source compile with node-gyp)
make: Entering directory '/home/pi/app/node_modules/sqlite3/build'

AND:

> CS5490@1.0.1 install /home/pi/app/node_modules/CS5490
> /bin/bash ./install.sh

make: Entering directory '/home/pi/app/node_modules/CS5490/build'
  CXX(target) Release/obj.target/CS5490/CS5490.o
../CS5490.cc: In function ‘void DriverVersion(const Nan::FunctionCallbackInfo<v8::Value>&)’:
../CS5490.cc:110:75: error: no matching function for call to ‘Nan::ReturnValue<v8::Value>::Set(v8::MaybeLocal<v8::String>)’
  info.GetReturnValue().Set(String::NewFromUtf8( isolate, version.c_str() ));
                                                                           ^

elektrolubach, 2020-12-29:
Hi @Jendemen,

I recently had the same errors during installing the PiPowerMeter software.
The last error is causing the above mentioned errors I think.
I did not deep dive in, but this must have to do with the type of API for NodeJS (and its constraints and requirements) which is used here.

In the driver C++-Modules for the CS5463 (separate repository [here](https://github.com/crjens/cs5463), file CS5463.cc, line 517) or the CS5490 ([here](https://github.com/crjens/CS5490), file CS5490.cc, line 110) I changed the following line:
`info.GetReturnValue().Set(String::NewFromUtf8( isolate, version.c_str() ));`
to
`info.GetReturnValue().Set(String::NewFromUtf8( isolate, version.c_str() ).ToLocalChecked());`
I changed these files locally after downloading the software to my Pi using the wget command.

Afterwards I re-built these modules the PiPowerMeter software with `npm install` and I got it working.

Maybe this helps you as well...
Cheers elektrolubach

Jendemen, 2020-12-30:
Hi @elektrolubach,

That did the job. Albeit lots of warnings I now can start the webpage.

Thanks a lot!

Closed 2021-01-02.

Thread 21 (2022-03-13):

Install Pi meter issue

dorseyn, 2022-03-13:
When install using the latest instructions I receive the following error during the install process --

wiringpi-latest.deb                       100%[=====================================================================================>]  51.04K   224KB/s    in 0.2s

2022-03-13 12:52:17 (224 KB/s) - ‘wiringpi-latest.deb’ saved [52260/52260]

Selecting previously unselected package wiringpi.
(Reading database ... 40126 files and directories currently installed.)
Preparing to unpack wiringpi-latest.deb ...
Unpacking wiringpi (2.52) ...
Setting up wiringpi (2.52) ...
Processing triggers for man-db (2.8.5-2) ...
>>> Install PiPowerMeter
bash: line 32: git: command not found
bash: line 33: cd: app: No such file or directory
npm ERR! code ENOENT
npm ERR! syscall open
npm ERR! path /home/pi/package.json
npm ERR! errno -2
npm ERR! enoent ENOENT: no such file or directory, open '/home/pi/package.json'
npm ERR! enoent This is related to npm not being able to find a file.
npm ERR! enoent

npm ERR! A complete log of this run can be found in:
npm ERR!     /home/pi/.npm/_logs/2022-03-13T16_52_29_821Z-debug-0.log
>>> PiPowerMeter is installed
>>> Restarting...

So when I use the URL to access the GUI I receive the message "This site can’t be reached"

stampeder, 2025-03-23:
Did you ever get this working?

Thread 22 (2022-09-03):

Fresh install errors / no readings

chillr21, 2022-09-03:
Hi there,

Just tried to do a fresh install of the current version of PiPowerMeter but can not get it to work correctly (I'm back to using my old version via a disk img I had created back in 2019 - `PiPowerMeter Software timestamp: 018-11-26T02:58:19.000Z`).

The installer seems to complete without any errors, it does hang for a while here and there thou.

Once installed and rebooted the web page is accessible but no power readings can be obtained and the nodejs.err.log has the following error:

```
Error: Cannot find module '/home/pi/app/node_modules/CS5490/build/Release/CS5490.node'. Please verify that the package.json has a valid "main" entry
    at tryPackage (node:internal/modules/cjs/loader:364:19)
    at Function.Module._findPath (node:internal/modules/cjs/loader:577:18)
    at Function.Module._resolveFilename (node:internal/modules/cjs/loader:942:27)
    at Function.Module._load (node:internal/modules/cjs/loader:804:27)
    at Module.require (node:internal/modules/cjs/loader:1028:19)
    at require (node:internal/modules/cjs/helpers:102:18)
    at Object.<anonymous> (/home/pi/app/CS5490.js:3:14)
    at Module._compile (node:internal/modules/cjs/loader:1126:14)
    at Object.Module._extensions..js (node:internal/modules/cjs/loader:1180:10)
    at Module.load (node:internal/modules/cjs/loader:1004:32) {
  code: 'MODULE_NOT_FOUND',
  path: '/home/pi/app/node_modules/CS5490/package.json',
  requestPath: 'CS5490'
}
node:events:491
      throw er; // Unhandled 'error' event
      ^

Error [ERR_IPC_CHANNEL_CLOSED]: Channel closed
    at new NodeError (node:internal/errors:387:5)
    at ChildProcess.target.send (node:internal/child_process:742:16)
    at /home/pi/app/driver.js:170:20
    at /home/pi/app/database.js:874:37
    at Statement.<anonymous> (/home/pi/app/database.js:605:17)
Emitted 'error' event on ChildProcess instance at:
    at node:internal/child_process:746:35
    at processTicksAndRejections (node:internal/process/task_queues:78:11) {
  code: 'ERR_IPC_CHANNEL_CLOSED'
}
node:internal/modules/cjs/loader:372
      throw err;
      ^

Error: Cannot find module '/home/pi/app/node_modules/CS5490/build/Release/CS5490.node'. Please verify that the package.json has a valid "main" entry
    at tryPackage (node:internal/modules/cjs/loader:364:19)
    at Function.Module._findPath (node:internal/modules/cjs/loader:577:18)
    at Function.Module._resolveFilename (node:internal/modules/cjs/loader:942:27)
    at Function.Module._load (node:internal/modules/cjs/loader:804:27)
    at Module.require (node:internal/modules/cjs/loader:1028:19)
    at require (node:internal/modules/cjs/helpers:102:18)
    at Object.<anonymous> (/home/pi/app/CS5490.js:3:14)
    at Module._compile (node:internal/modules/cjs/loader:1126:14)
    at Object.Module._extensions..js (node:internal/modules/cjs/loader:1180:10)
    at Module.load (node:internal/modules/cjs/loader:1004:32) {
  code: 'MODULE_NOT_FOUND',
  path: '/home/pi/app/node_modules/CS5490/package.json',
  requestPath: 'CS5490'
}
```

Fresh install details:
Rpi 3B 1GB
SD card flashed with official image - "2021-03-04-raspios-buster-armhf-lite.img"
Logged on as pi then executed: `wget -O - https://raw.githubusercontent.com/crjens/PiPowerMeter/master/setup.sh | bash`

soup-campbell, 2023-09-06:
Same Problem. Error: Cannot find module '/home/pi/app/node_modules/CS5490/build/Release/CS5490.node  Power Meter does not start.. No entries made to powermeter.db. In addition, some of the dependancies should be updated.
wiringpi- is no longer current

overpaul, 2024-12-23:
Chillr21 - any hance of getting a copy of your SD backup image?  I lost my SD card and can not reload the system.  I have my data, but no SD card image.

chillr21, 2024-12-23:
> Chillr21 - any hance of getting a copy of your SD backup image? I lost my SD card and can not reload the system. I have my data, but no SD card image.

Sure, how do you propose I share it for you to grab it?

overpaul, 2024-12-24:
Thats great.

Can you upload it to Dropbox or Google Drive or another file sharing option.
If you give me your email, I can open up a folder on my Google Drive that
you can upload to
I could also mail you an SD card that you can copy the image to.

However we do it, it will save me a lot of work and save my power monitor.
Thanks

*Paul Oversmith*

***@***.*** ***@***.***>*
*941-266-3600*

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

chillr21, 2024-12-24:
OK, I've tried sending an SMS with details to your phone number

soup-campbell, 2024-12-24:
It will take me a couple of days to locate it. I have not looked at it in over a year.-Soup-
    On Monday, December 23, 2024 at 08:36:32 PM GMT-5, chillr21 ***@***.***> wrote:

OK, I've tried sending an SMS with details to your phone number

—
Reply to this email directly, view it on GitHub, or unsubscribe.
You are receiving this because you commented.Message ID: ***@***.***>

chillr21, 2024-12-24:
Or send the link to this address if it doesn't get filtered out:
pigekey120
at
chosenz
dot
com

soup-campbell, 2024-12-24:
I am sorry, I don't think I have what you were looking for. My interest was writing a datalogger centered around the CS5490. The human interface and server portions of that posting were of no interest to me. I never did pursue the problems I was having with the download.-Soup-
    On Monday, December 23, 2024 at 09:36:33 PM EST, chillr21 ***@***.***> wrote:

Or send the link to this address if it doesn't get filtered out:
pigekey120
at
chosenx
dot
com

—
Reply to this email directly, view it on GitHub, or unsubscribe.
You are receiving this because you commented.Message ID: ***@***.***>

stampeder, 2025-03-23:
Has anyone got this working recently?
Thanks.
Glenn

soup-campbell, 2025-03-23:
no
    On Sunday, March 23, 2025 at 01:12:41 AM GMT-5, Glenn ***@***.***> wrote:

Has anyone got this working recently?
Thanks.
Glenn

—
Reply to this email directly, view it on GitHub, or unsubscribe.
You are receiving this because you commented.Message ID: ***@***.***>
stampeder left a comment (crjens/PiPowerMeter#22)
Has anyone got this working recently?
Thanks.
Glenn

—
Reply to this email directly, view it on GitHub, or unsubscribe.
You are receiving this because you commented.Message ID: ***@***.***>

overpaul, 2025-03-23:
I had a bad SD card and had to reload the software. I couldn't get it to
work. I posted on the forum, and a nice person sent me an image, which I
loaded and got it to work. I can't remember what the problem was; it could
have been outdated support software. I did save an image of the restored
version so that if I had a failure, I could go back to it.

*Paul Oversmith*

***@***.*** ***@***.***>*
*941-266-3600*

On Sun, Mar 23, 2025 at 9:06 AM soup-campbell ***@***.***>
wrote:

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

stampeder, 2025-03-23:
Could you send me a copy of the image?
Thanks.

overpaul, 2025-03-23:
Pleased to the file is 4 gig in size. (winRAR).
Not sure I can upload it on GitHub.
It has some custom mods to meet my needs, but it is basically the same.

I can try with email if you send me an e-mail address.

*Paul Oversmith*

***@***.*** ***@***.***>*
*941-266-3600*

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

stampeder, 2025-03-24:
Thanks Paul. My email is gtracy@peoplescom.net. Let's try that.

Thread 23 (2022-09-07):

Few watts remanence

jburdy, 2022-09-07:
Hello,

On some of my probes I have a few watts of remanence while nothing is consumed (2x93W in the example attached). Do you have any idea where this could be coming from? How can I investigate? Should I play with the "scale"? I didn't touch these values in practice.

Many thanks in advance (for the answer and for the product).

PS: I wrote to you for a board order 4 days ago, I don't know if you saw my email or if it's a spam problem again.

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

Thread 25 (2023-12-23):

Does someone still have some boards available

pleuba, 2023-12-23:
I'm using the power meter for several years, and really liked it, but recently faced an issue on an jack connector.

I'm looking more specifically for the 16 channel input board. I tried to contact @crjens by email, but without success.

So if someone has one available, please contact me.

Philippe

jburdy, 2023-12-23:
I can't help you, but I wanted to share that I'm worried. Like you, I'm very happy with it, it's been running for 5 years.
I tried to contact crjens last year to buy another one as a backup but got no response...

I wonder if we shouldn't kindly find a better distributed alternative...

stampeder, 2025-05-05:
I know this is an old thread. I have had my pipowermeter controller board and one i/o board sitting for several years and  I would like to get them going. I need a working image of an sd card that I can spin up please. I have tried installing from scratch without success.
Thanks.
Glenn...

pleuba, 2025-09-22:
> [@pleuba](https://github.com/pleuba) [@jburdy](https://github.com/jburdy) guys i've got a powerboard and 16ch available if you still want one.

Yes, I’m intrrested

stampeder, 2025-09-22:
gtracy@peoplescom.net

pleuba, 2025-09-22:
> [@pleuba](https://github.com/pleuba) Mate whats your email? @rhyst9 pleuba_at_swissonline.ch

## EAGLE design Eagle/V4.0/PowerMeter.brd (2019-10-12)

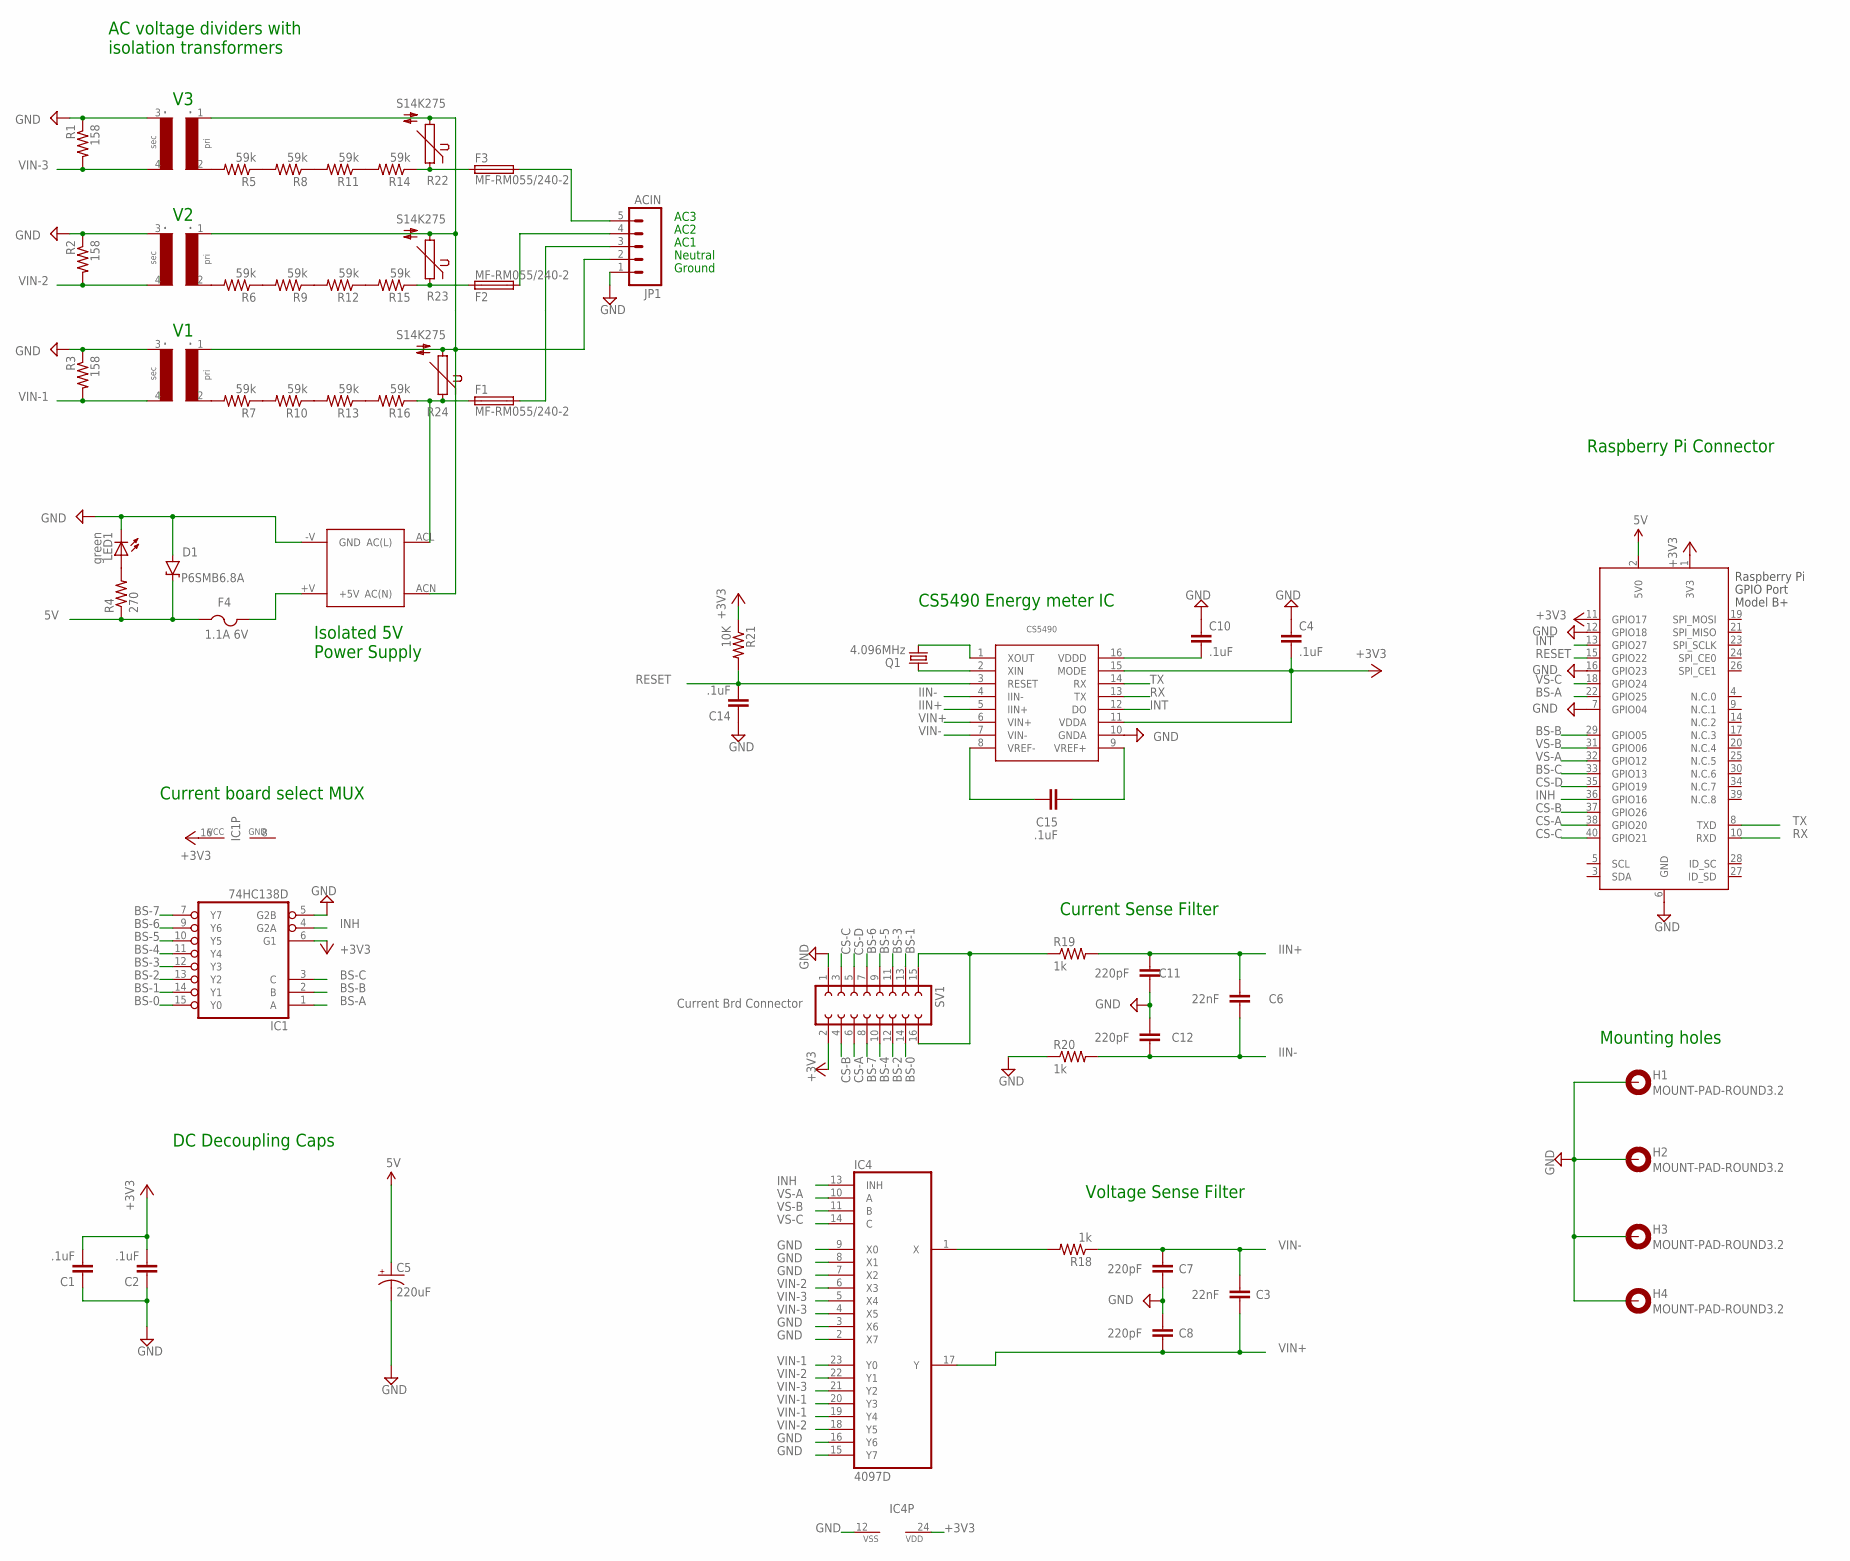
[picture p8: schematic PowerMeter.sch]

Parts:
C1, C2, C4, C10, C14, C15: .1uF; C1206; PARTNO C1206C104K5RAC7867
C3, C6: 22nF; C1206; PARTNO C1206C221J5GACTU
C5: 220uF; PANASONIC_D; PARTNO ESH227M016AE3AA
C7, C8, C11, C12: 220pF; C1206; PARTNO C1206C221J5GACTU
CS5490: CS5490; SOIC127P600X175-16N
D1: P6SMB6.8A; DO-214AA; PARTNO P6KE6.8A
F1, F2, F3: MF-RM055/240-2; TE5; PARTNO MF-RM055/240-2
F4: 1.1A 6V; 1812; PARTNO 0ZCC0110AF2C
H1, H2, H3, H4: MOUNT-PAD-ROUND3.2; 3,2-PAD
IC1: 74HC138D; SO16; PARTNO SN74HC138NSR
IC4: 4097D; SO24W
JP1: ACIN; SCREWTERMINAL-5MM-5; PARTNO 1935190
LED1: green; LED_1206; PARTNO LTST-C150GKT
Q1: 4.096MHz; HC49UP; PARTNO 9B-4.096MBBK-B
R1, R2, R3: 158; R1206; PARTNO RC1206FR-07158RL
R4: 270; R1206; PARTNO RC1206FR-07270RL
R5, R6, R7, R8, R9, R10, R11, R12, R13, R14, R15, R16: 59k; R1206; PARTNO RC1206FR-071KL
R18, R19, R20: 1k; R1206; PARTNO RC1206FR-071KL
R21: 10K; R1206; PARTNO RC1206FR-0710KL
R22, R23, R24: S14K275
SV1: Current Brd Connector; FE08-2; PARTNO PPTC082LFBN-RC
T1, T2, T3: TV16E
U$1: IRM-10
X1: RASPI_BOARD_B+_E4; RASPI_BOARD_B+_EDGES_4DRILL; PARTNO M20-9762046

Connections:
5V: C5.+, D1.C, F4.1, R4.1, X1.2 (5V0)
+3V3: C1.2, C2.2, C4.2, CS5490.11 (VDDA), CS5490.15 (MODE), IC1.6 (G1), IC1.16 (VCC), IC4.24 (VDD), R21.1, SV1.2, X1.1 (3V3), X1.11 (GPIO17)
+5V: F4.2, U$1.+V (+5V)
AC(L): F1.1, R16.1, R24.1, U$1.ACL (AC(L))
AC(N): JP1.2 (4), R22.2, R23.2, R24.2, T1.1, T2.1, T3.1, U$1.ACN (AC(N))
BS-0: IC1.15 (Y0), SV1.14
BS-1: IC1.14 (Y1), SV1.13
BS-2: IC1.13 (Y2), SV1.12
BS-3: IC1.12 (Y3), SV1.11
BS-4: IC1.11 (Y4), SV1.10
BS-5: IC1.10 (Y5), SV1.9
BS-6: IC1.9 (Y6), SV1.7
BS-7: IC1.7 (Y7), SV1.8
BS-A: IC1.1 (A), X1.22 (GPIO25)
BS-B: IC1.2 (B), X1.29 (GPIO05)
BS-C: IC1.3 (C), X1.33 (GPIO13)
CS-A: SV1.6, X1.38 (GPIO20)
CS-B: SV1.4, X1.37 (GPIO26)
CS-C: SV1.3, X1.40 (GPIO21)
CS-D: SV1.5, X1.35 (GPIO19)
GND: C1.1, C2.1, C4.1, C5.-, C7.1, C8.2, C10.1, C11.1, C12.2, C14.1, CS5490.10 (GNDA), D1.A, H1.B3,2, H2.B3,2, H3.B3,2, H4.B3,2, IC1.5 (G2B), IC1.8 (GND), IC4.2 (X7), IC4.3 (X6), IC4.7 (X2), IC4.8 (X1), IC4.9 (X0), IC4.12 (VSS), IC4.15 (Y7), IC4.16 (Y6), JP1.1 (5), LED1.C, R1.1, R2.1, R3.1, R20.1, SV1.1, T1.3, T2.3, T3.3, U$1.-V (GND), X1.6 (GND), X1.7 (GPIO04), X1.12 (GPIO18), X1.16 (GPIO23)
IIN+: C6.2, C11.2, CS5490.5 (IIN+), R19.2
IIN-: C6.1, C12.1, CS5490.4 (IIN-), R20.2
INH: IC1.4 (G2A), IC4.13 (INH), X1.36 (GPIO16)
INT: CS5490.12 (DO), X1.13 (GPIO27)
unnamed: CS5490.2 (XIN), Q1.1
unnamed: F2.1, R15.1, R23.1
unnamed: R5.1, R8.2
unnamed: R8.1, R11.2
unnamed: F1.2, JP1.3
unnamed: R9.1, R12.2
unnamed: LED1.A, R4.2
unnamed: IC4.1 (X), R18.2
unnamed: F3.2, JP1.5 (1)
unnamed: R13.1, R16.2
unnamed: R7.2, T3.2
unnamed: CS5490.1 (XOUT), Q1.2
unnamed: R7.1, R10.2
unnamed: R10.1, R13.2
unnamed: R6.2, T2.2
unnamed: R6.1, R9.2
unnamed: C10.2, CS5490.16 (VDDD)
unnamed: R12.1, R15.2
unnamed: R5.2, T1.2
unnamed: R11.1, R14.2
unnamed: F3.1, R14.1, R22.1
unnamed: R19.1, SV1.15, SV1.16
unnamed: C15.1, CS5490.8 (VREF-)
unnamed: C15.2, CS5490.9 (VREF+)
unnamed: F2.2, JP1.4 (2)
RESET: C14.2, CS5490.3 (RESET), R21.2, X1.15 (GPIO22)
RX: CS5490.13 (TX), X1.10 (RXD)
TX: CS5490.14 (RX), X1.8 (TXD)
VIN+: C3.1, C8.1, CS5490.6 (VIN+), IC4.17 (Y)
VIN-: C3.2, C7.2, CS5490.7 (VIN-), R18.1
VIN-1: IC4.19 (Y4), IC4.20 (Y3), IC4.23 (Y0), R3.2, T3.4
VIN-2: IC4.6 (X3), IC4.18 (Y5), IC4.22 (Y1), R2.2, T2.4
VIN-3: IC4.4 (X5), IC4.5 (X4), IC4.21 (Y2), R1.2, T1.4
VS-A: IC4.10 (A), X1.32 (GPIO12)
VS-B: IC4.11 (B), X1.31 (GPIO06)
VS-C: IC4.14 (C), X1.18 (GPIO24)

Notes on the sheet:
AC voltage dividers with isolation transformers
Isolated 5V Power Supply
DC Decoupling Caps
Raspberry Pi Connector
CS5490 Energy meter IC
Voltage Sense Filter
Current Sense Filter
Current board select MUX
Mounting holes
AC1
AC2
AC3
Neutral
Ground

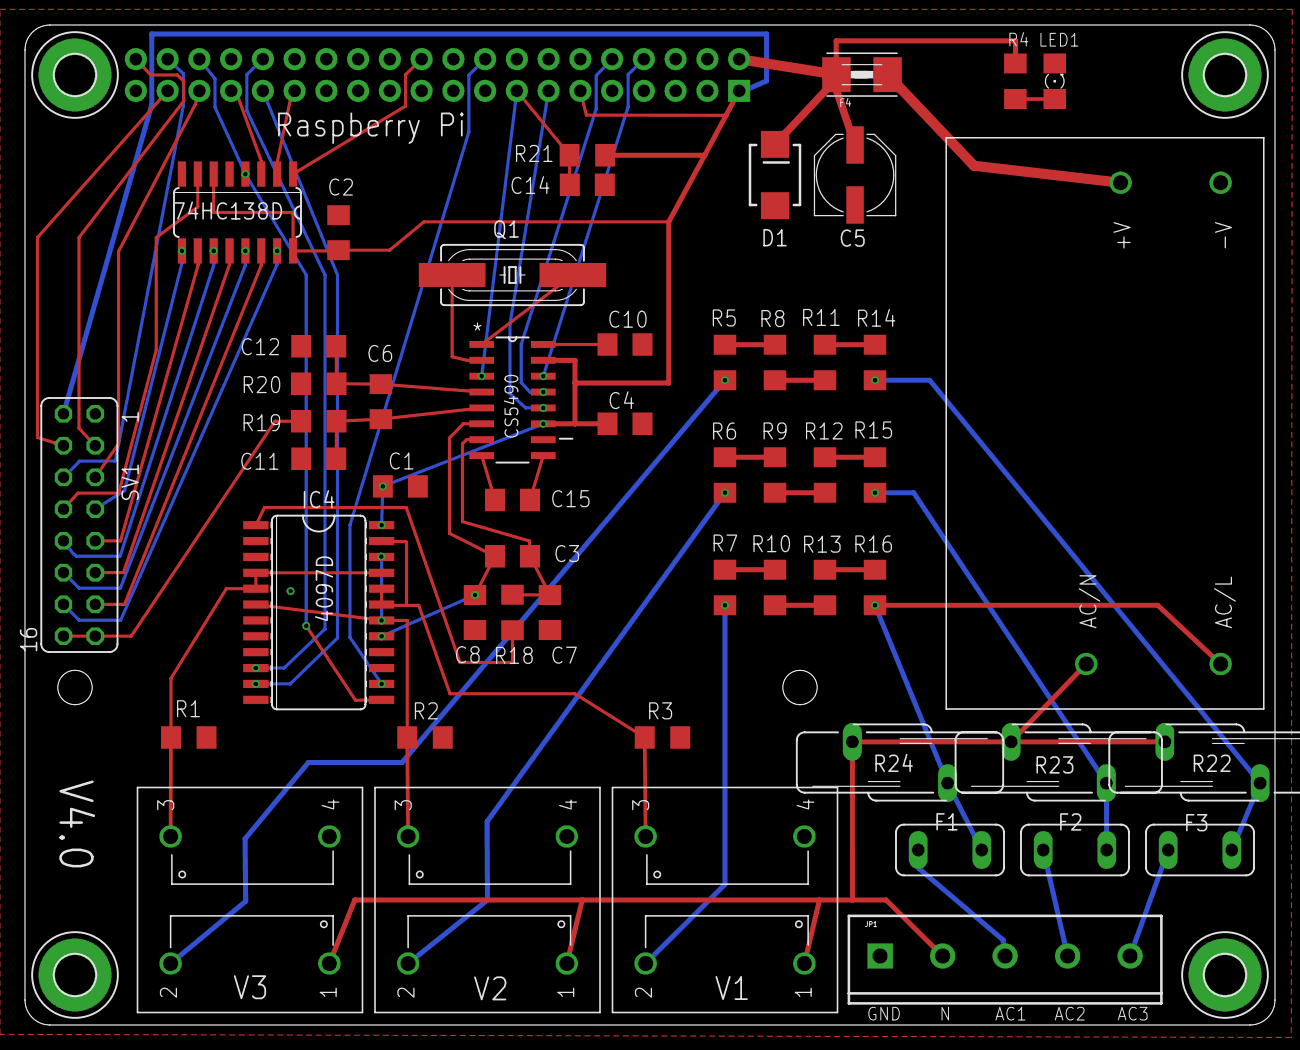
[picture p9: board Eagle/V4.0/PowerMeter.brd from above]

Board: 2 copper layers, 100.0 x 80.0 mm, 57 parts (1 on the bottom side), 61 nets.

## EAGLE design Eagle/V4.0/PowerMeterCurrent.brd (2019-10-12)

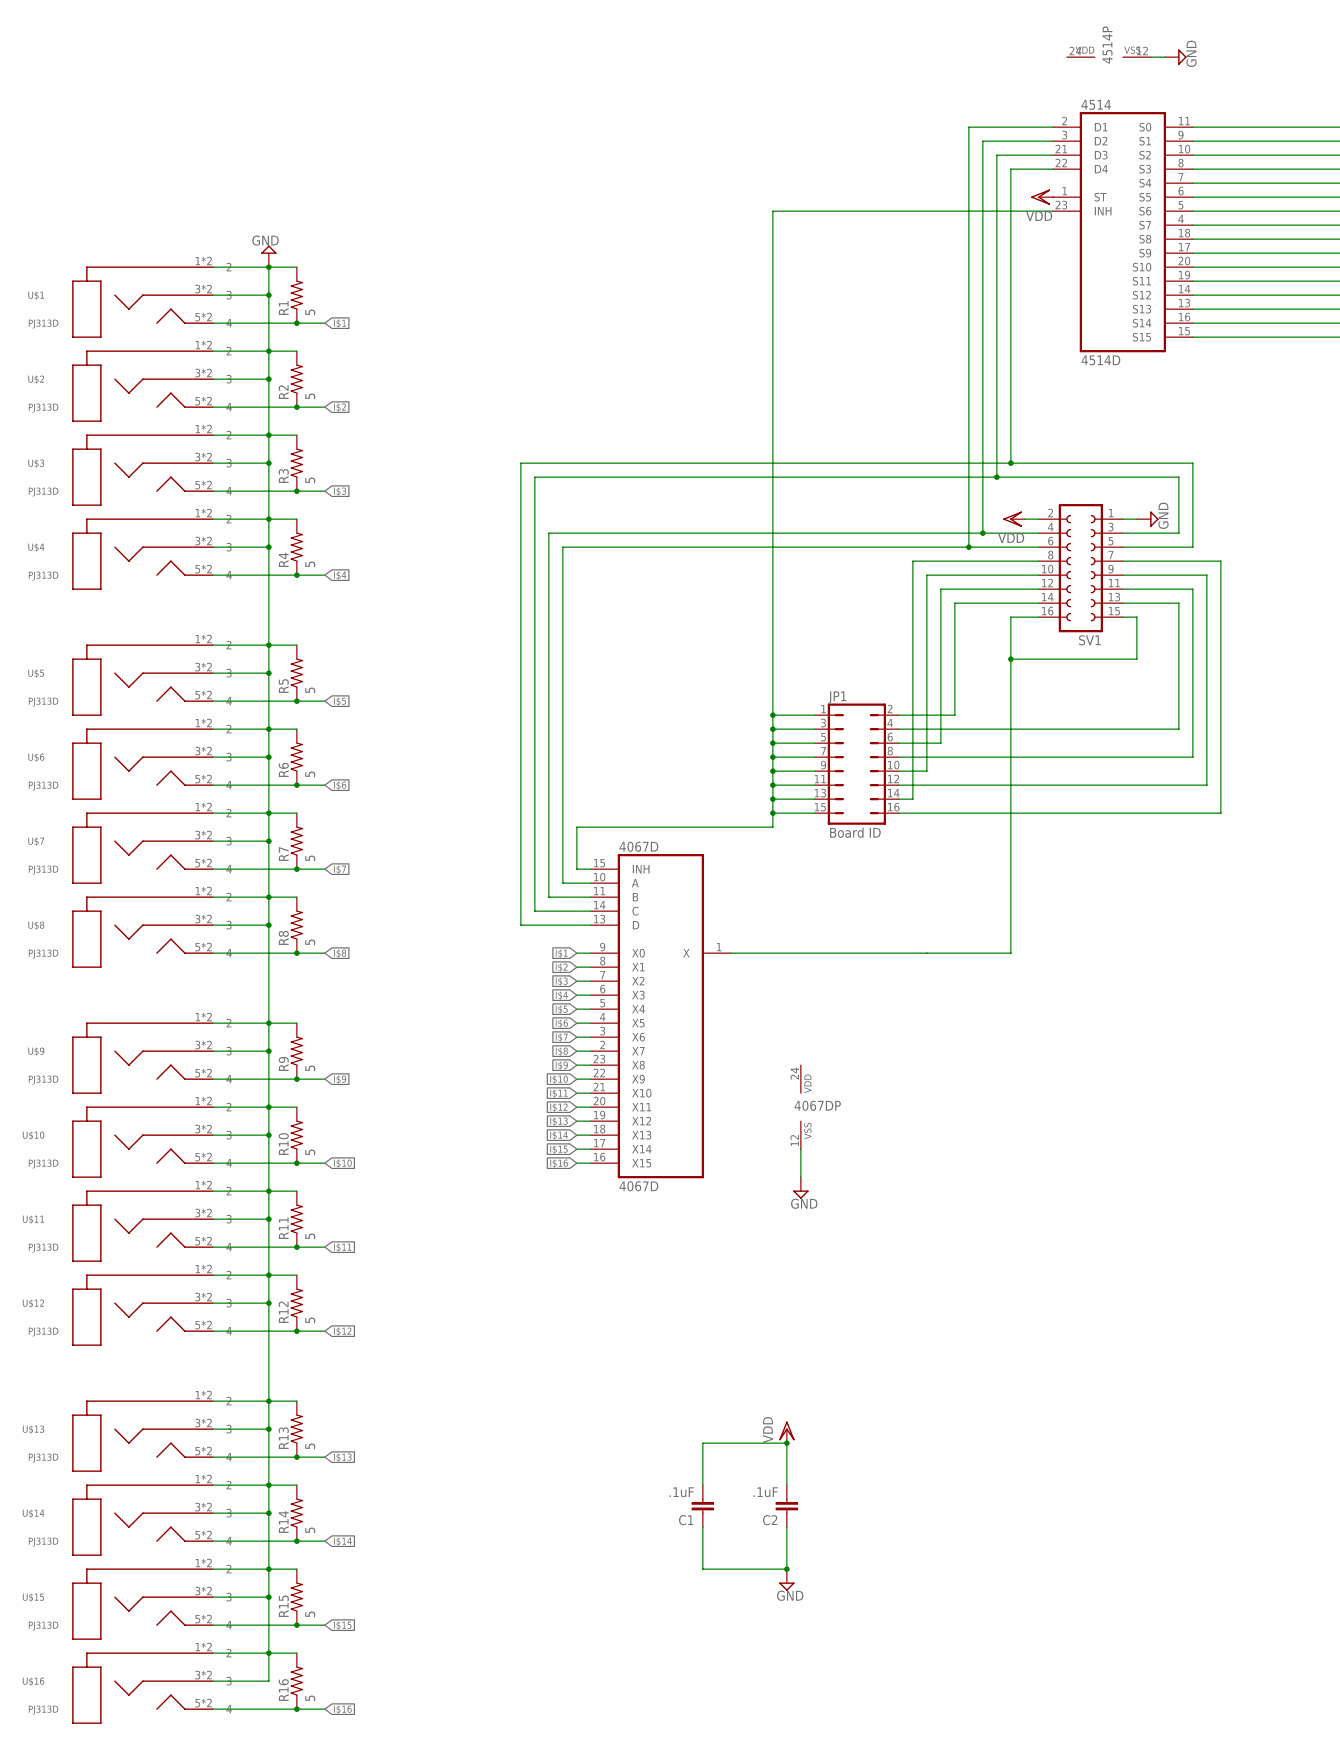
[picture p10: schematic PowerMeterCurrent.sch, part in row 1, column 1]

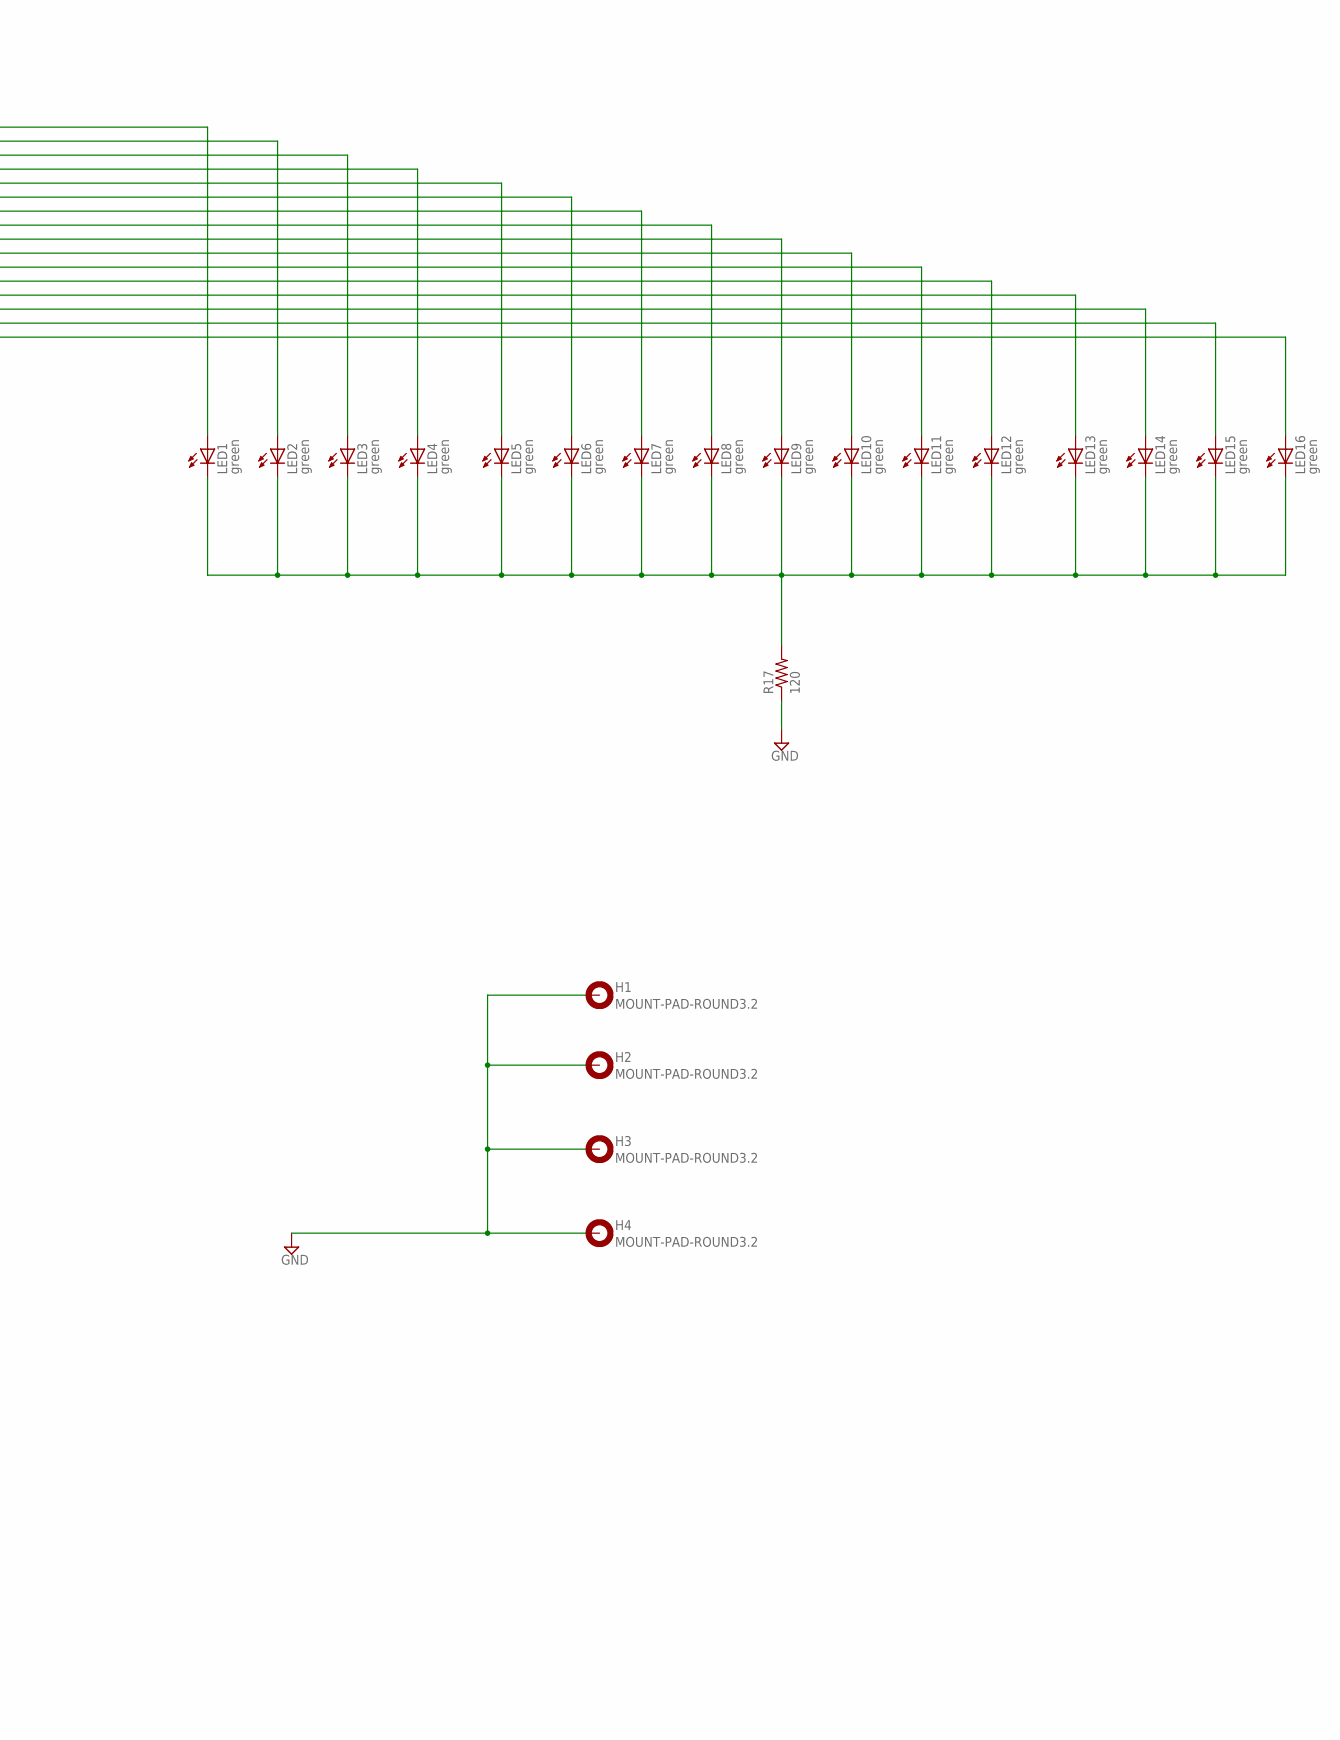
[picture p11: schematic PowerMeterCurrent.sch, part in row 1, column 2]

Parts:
4067D: 4067D; SO24W; PARTNO 74HC4067D,652
4514: 4514D; SO24W; PARTNO 74HC154D,652
C1, C2: .1uF; C1206; PARTNO C1206C104K5RAC7867
H1, H2, H3, H4: MOUNT-PAD-ROUND3.2; 3,2-PAD
JP1: Board ID; JP8Q; PARTNO 67996-416HLF
LED1, LED2, LED3, LED4, LED5, LED6, LED7, LED8, LED9, LED10, LED11, LED12, LED13, LED14, LED15, LED16: green; LED_1206; PARTNO LTST-C150GKT
R1, R2, R3, R4, R5, R6, R7, R8, R9, R10, R11, R12, R13, R14, R15, R16: 5; R1206; PARTNO RC1206FR-077R5L
R17: 120; R1206; PARTNO RC1206FR-07120RL
SV1: FE08-2; PARTNO SSQ-108-02-T-D
U$1, U$2, U$3, U$4, U$5, U$6, U$7, U$8, U$9, U$10, U$11, U$12, U$13, U$14, U$15, U$16: PJ313D

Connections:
GND: 4067D.12 (VSS), 4514.12 (VSS), C1.1, C2.1, H1.B3,2, H2.B3,2, H3.B3,2, H4.B3,2, R1.2, R2.2, R3.2, R4.2, R5.2, R6.2, R7.2, R8.2, R9.2, R10.2, R11.2, R12.2, R13.2, R14.2, R15.2, R16.2, R17.1, SV1.1, U$1.1 (2), U$1.2, U$1.3, U$1.4 (3), U$2.1 (2), U$2.2, U$2.3, U$2.4 (3), U$3.1 (2), U$3.2, U$3.3, U$3.4 (3), U$4.1 (2), U$4.2, U$4.3, U$4.4 (3), U$5.1 (2), U$5.2, U$5.3, U$5.4 (3), U$6.1 (2), U$6.2, U$6.3, U$6.4 (3), U$7.1 (2), U$7.2, U$7.3, U$7.4 (3), U$8.1 (2), U$8.2, U$8.3, U$8.4 (3), U$9.1 (2), U$9.2, U$9.3, U$9.4 (3), U$10.1 (2), U$10.2, U$10.3, U$10.4 (3), U$11.1 (2), U$11.2, U$11.3, U$11.4 (3), U$12.1 (2), U$12.2, U$12.3, U$12.4 (3), U$13.1 (2), U$13.2, U$13.3, U$13.4 (3), U$14.1 (2), U$14.2, U$14.3, U$14.4 (3), U$15.1 (2), U$15.2, U$15.3, U$15.4 (3), U$16.1 (2), U$16.2, U$16.3, U$16.4 (3)
I$1: 4067D.9 (X0), R1.1, U$1.5 (4), U$1.6 (4)
I$2: 4067D.8 (X1), R2.1, U$2.5 (4), U$2.6 (4)
I$3: 4067D.7 (X2), R3.1, U$3.5 (4), U$3.6 (4)
I$4: 4067D.6 (X3), R4.1, U$4.5 (4), U$4.6 (4)
I$5: 4067D.5 (X4), R5.1, U$5.5 (4), U$5.6 (4)
I$6: 4067D.4 (X5), R6.1, U$6.5 (4), U$6.6 (4)
I$7: 4067D.3 (X6), R7.1, U$7.5 (4), U$7.6 (4)
I$8: 4067D.2 (X7), R8.1, U$8.5 (4), U$8.6 (4)
I$9: 4067D.23 (X8), R9.1, U$9.5 (4), U$9.6 (4)
I$10: 4067D.22 (X9), R10.1, U$10.5 (4), U$10.6 (4)
I$11: 4067D.21 (X10), R11.1, U$11.5 (4), U$11.6 (4)
I$12: 4067D.20 (X11), R12.1, U$12.5 (4), U$12.6 (4)
I$13: 4067D.19 (X12), R13.1, U$13.5 (4), U$13.6 (4)
I$14: 4067D.18 (X13), R14.1, U$14.5 (4), U$14.6 (4)
I$15: 4067D.17 (X14), R15.1, U$15.5 (4), U$15.6 (4)
I$16: 4067D.16 (X15), R16.1, U$16.5 (4), U$16.6 (4)
unnamed: 4067D.10 (A), 4514.2 (D1), SV1.6
unnamed: 4514.11 (S0), LED1.A
unnamed: 4067D.11 (B), 4514.3 (D2), SV1.4
unnamed: 4067D.14 (C), 4514.21 (D3), SV1.3
unnamed: 4067D.13 (D), 4514.22 (D4), SV1.5
unnamed: 4067D.15 (INH), 4514.23 (INH), JP1.1, JP1.3, JP1.5, JP1.7, JP1.9, JP1.11, JP1.13, JP1.15
unnamed: JP1.14, SV1.8
unnamed: JP1.10, SV1.10
unnamed: 4514.9 (S1), LED2.A
unnamed: JP1.6, SV1.12
unnamed: JP1.2, SV1.14
unnamed: 4067D.1 (X), SV1.15, SV1.16
unnamed: JP1.4, SV1.13
unnamed: JP1.8, SV1.11
unnamed: JP1.12, SV1.9
unnamed: JP1.16, SV1.7
unnamed: 4514.10 (S2), LED3.A
unnamed: LED1.C, LED2.C, LED3.C, LED4.C, LED5.C, LED6.C, LED7.C, LED8.C, LED9.C, LED10.C, LED11.C, LED12.C, LED13.C, LED14.C, LED15.C, LED16.C, R17.2
unnamed: 4514.8 (S3), LED4.A
unnamed: 4514.7 (S4), LED5.A
unnamed: 4514.6 (S5), LED6.A
unnamed: 4514.5 (S6), LED7.A
unnamed: 4514.4 (S7), LED8.A
unnamed: 4514.18 (S8), LED9.A
unnamed: 4514.17 (S9), LED10.A
unnamed: 4514.20 (S10), LED11.A
unnamed: 4514.19 (S11), LED12.A
unnamed: 4514.14 (S12), LED13.A
unnamed: 4514.13 (S13), LED14.A
unnamed: 4514.16 (S14), LED15.A
unnamed: 4514.15 (S15), LED16.A
VDD: 4067D.24 (VDD), 4514.1 (ST), 4514.24 (VDD), C1.2, C2.2, SV1.2

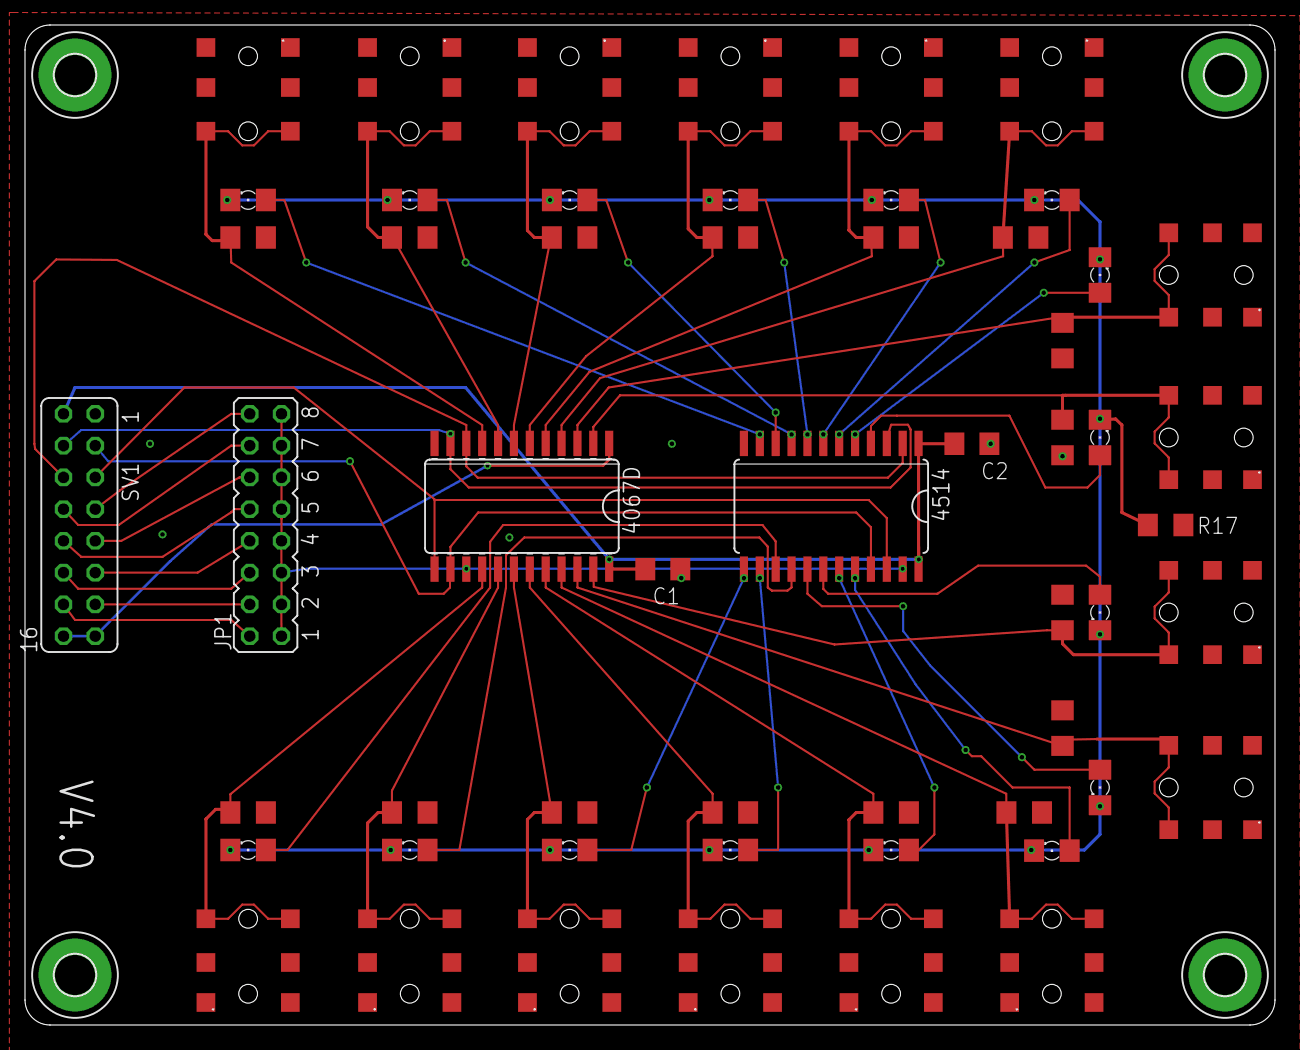
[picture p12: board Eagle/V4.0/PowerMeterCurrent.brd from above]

Board: 2 copper layers, 100.0 x 80.0 mm, 59 parts (0 on the bottom side), 49 nets.

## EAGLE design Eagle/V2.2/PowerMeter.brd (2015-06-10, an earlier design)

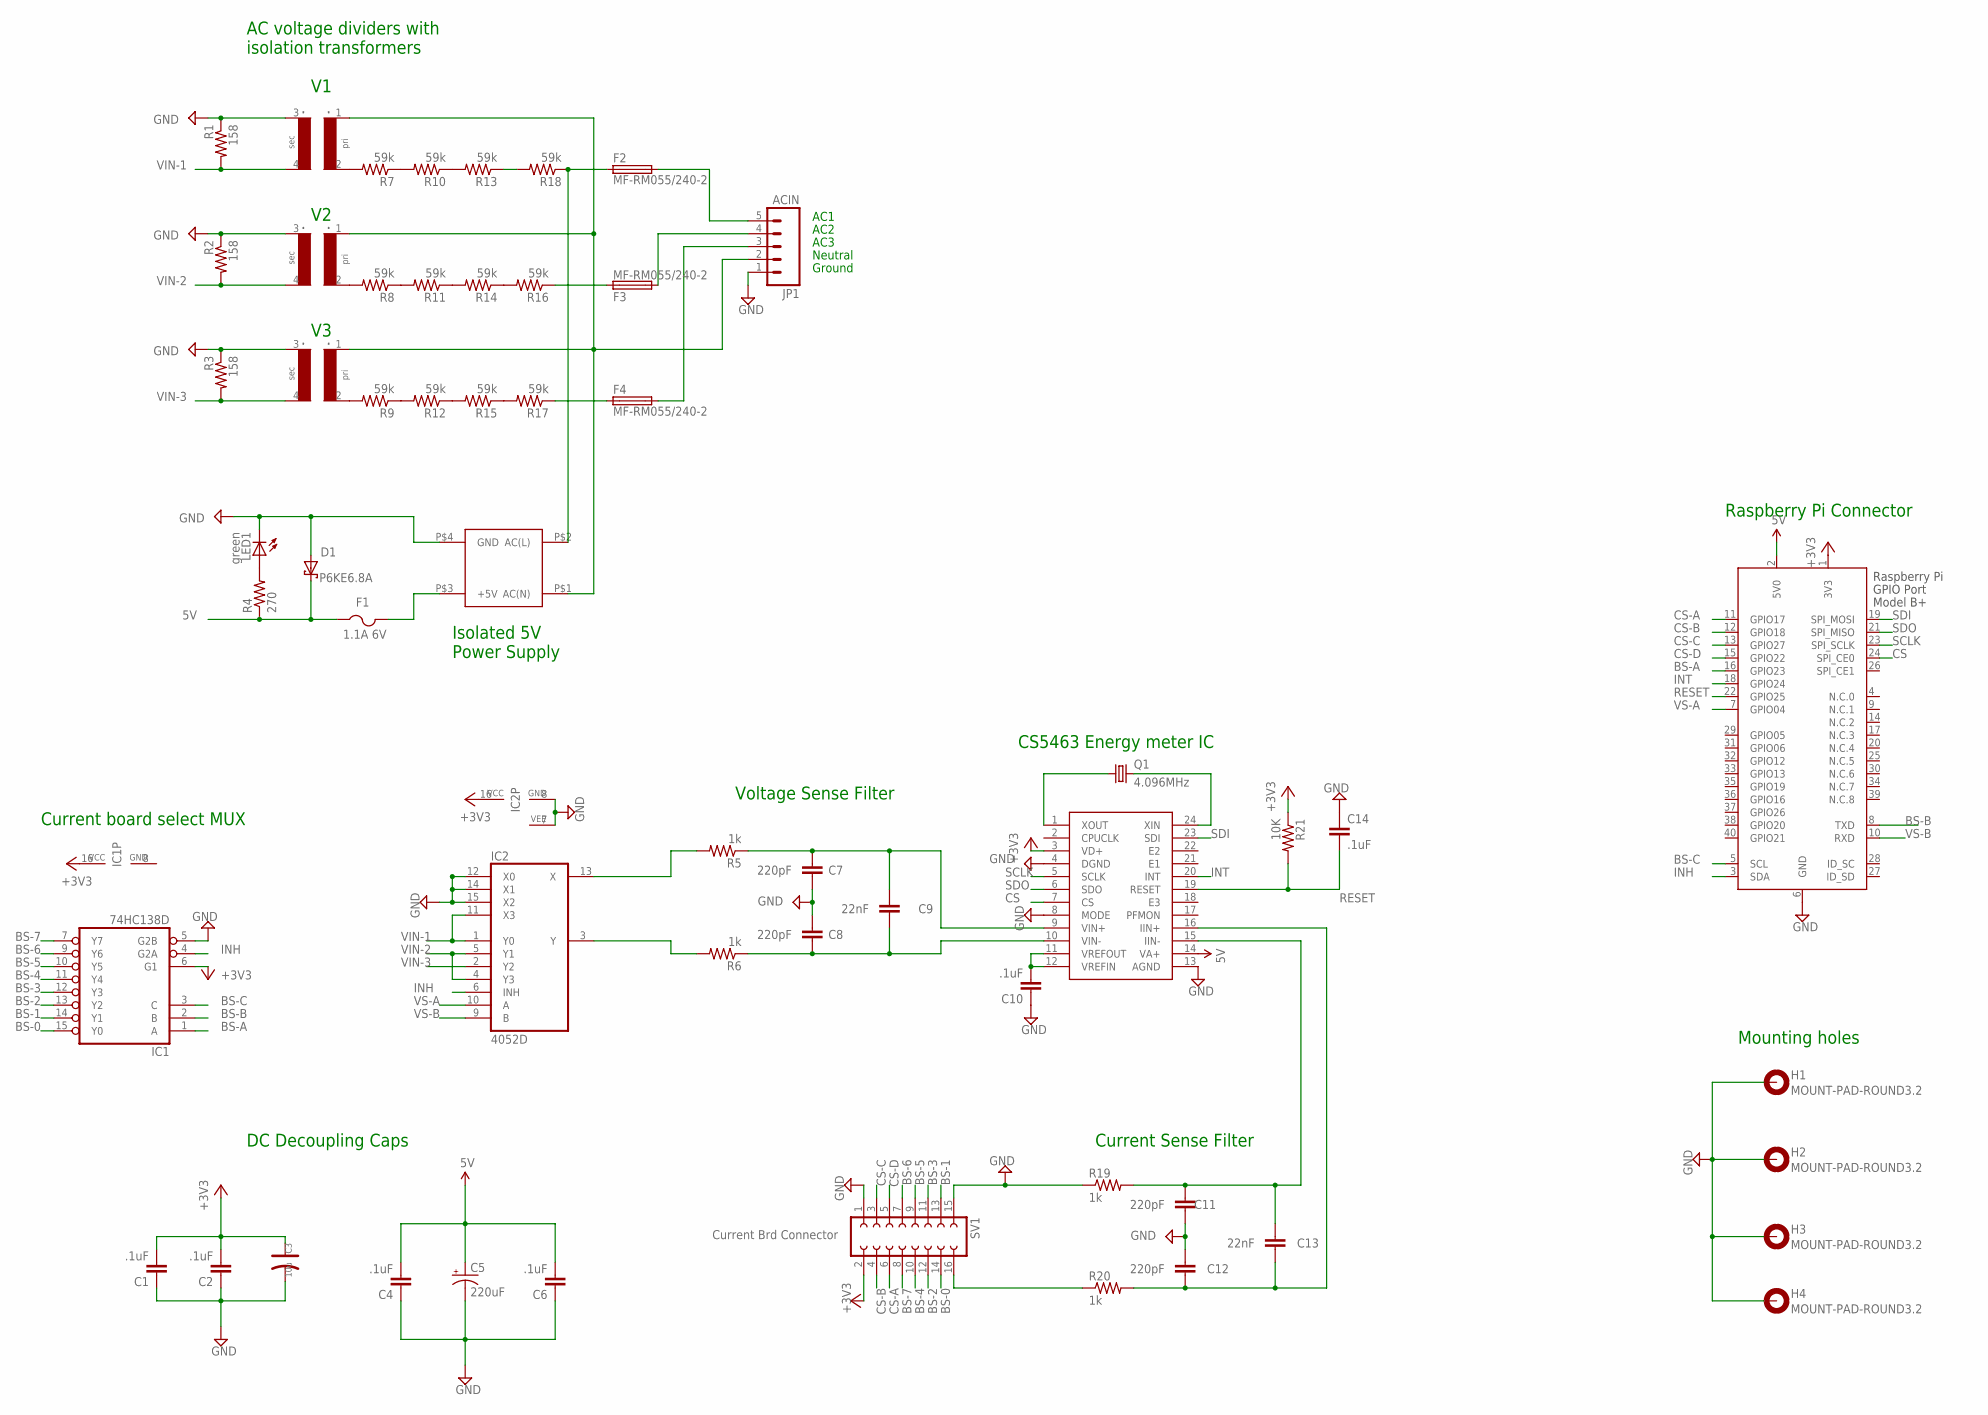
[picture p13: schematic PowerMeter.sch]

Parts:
C1, C2, C4, C6, C10, C14: .1uF; C1206; PARTNO C1206C104K5RAC7867
C3: 10u; AVX-C; PARTNO T491C106K016AT
C5: 220uF; E2,5-6E; PARTNO ESH227M016AE3AA
C7, C8, C11, C12: 220pF; C1206; PARTNO C1206C221J5GACTU
C9, C13: 22nF; C1206; PARTNO C1206C223K5RACTU
D1: P6KE6.8A; C1702-15; PARTNO P6KE6.8A
F1: 1.1A 6V; 1812; PARTNO 0ZCC0110AF2C
F2, F3, F4: MF-RM055/240-2; TE5; PARTNO MF-RM055/240-2
H1, H2, H3, H4: MOUNT-PAD-ROUND3.2; 3,2-PAD
IC1: 74HC138D; SO16; PARTNO SN74HC138NSR
IC2: 4052D; SO16; PARTNO CD4052BNSR
IC3: CS5463; SSOP24; PARTNO CS5463-ISZ
JP1: ACIN; SCREWTERMINAL-5MM-5; PARTNO 1935190
LED1: green; LED_1206; PARTNO LTST-C150GKT
PS1: VSK-S10; PARTNO VSK-S5-5UA
Q1: 4.096MHz; HC49/S; PARTNO 9B-4.096MBBK-B
R1, R2, R3: 158; R1206; PARTNO RC1206FR-07158RL
R4: 270; R1206; PARTNO RC1206FR-07270RL
R5, R6, R19, R20: 1k; R1206; PARTNO RC1206FR-071KL
R7, R8, R9, R10, R11, R12, R13, R14, R15, R16, R17, R18: 59k; R1206; PARTNO RC1206FR-071KL
R21: 10K; R1206; PARTNO RC1206FR-0710KL
SV1: Current Brd Connector; FE08-2; PARTNO PPTC082LFBN-RC
T1, T2, T3: TV16E
X1: RASPI_BOARD_B+_E4; RASPI_BOARD_B+_EDGES_4DRILL; PARTNO M20-9762046

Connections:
5V: C4.2, C5.+, C6.2, D1.C, F1.1, IC3.14 (VA+), R4.1, X1.2 (5V0)
+3V3: C1.2, C2.2, C3.+, IC1.6 (G1), IC1.16 (VCC), IC2.16 (VCC), IC3.3 (VD+), R21.1, SV1.2, X1.1 (3V3)
+5V: F1.2, PS1.P$3 (+5V)
AC(L): F2.1, PS1.P$2 (AC(L)), R18.1
AC(N): JP1.2 (4), PS1.P$1 (AC(N)), T1.1, T2.1, T3.1
BS-0: IC1.15 (Y0), SV1.14
BS-1: IC1.14 (Y1), SV1.13
BS-2: IC1.13 (Y2), SV1.12
BS-3: IC1.12 (Y3), SV1.11
BS-4: IC1.11 (Y4), SV1.10
BS-5: IC1.10 (Y5), SV1.9
BS-6: IC1.9 (Y6), SV1.7
BS-7: IC1.7 (Y7), SV1.8
BS-A: IC1.1 (A), X1.16 (GPIO23)
BS-B: IC1.2 (B), X1.8 (TXD)
BS-C: IC1.3 (C), X1.5 (SCL)
C5: C12.1, C13.1, IC3.16 (IIN+), R20.2
CS: IC3.7 (CS), X1.24 (SPI_CE0)
CS-A: SV1.6, X1.11 (GPIO17)
CS-B: SV1.4, X1.12 (GPIO18)
CS-C: SV1.3, X1.13 (GPIO27)
CS-D: SV1.5, X1.15 (GPIO22)
GND: C1.1, C2.1, C3.-, C4.1, C5.-, C6.1, C7.1, C8.2, C10.1, C11.1, C12.2, C14.1, D1.A, H1.B3,2, H2.B3,2, H3.B3,2, H4.B3,2, IC1.5 (G2B), IC1.8 (GND), IC2.7 (VEE), IC2.8 (GND), IC2.12 (X0), IC2.14 (X1), IC2.15 (X2), IC3.4 (DGND), IC3.8 (MODE), IC3.13 (AGND), JP1.1 (5), LED1.C, PS1.P$4 (GND), R1.1, R2.1, R3.1, R19.1, SV1.1, SV1.15, T1.3, T2.3, T3.3, X1.6 (GND)
IIN+: R20.1, SV1.16
INH: IC1.4 (G2A), IC2.6 (INH), X1.3 (SDA)
INT: IC3.20 (INT), X1.18 (GPIO24)
unnamed: IC3.1 (XOUT), Q1.1
unnamed: F3.1, R16.1
unnamed: R7.1, R10.2
unnamed: R10.1, R13.2
unnamed: F4.2, JP1.3
unnamed: R11.1, R14.2
unnamed: LED1.A, R4.2
unnamed: C11.2, C13.2, IC3.15 (IIN-), R19.2
unnamed: F2.2, JP1.5 (1)
unnamed: R15.1, R17.2
unnamed: R9.2, T3.2
unnamed: IC3.24 (XIN), Q1.2
unnamed: R9.1, R12.2
unnamed: R12.1, R15.2
unnamed: R8.2, T2.2
unnamed: R8.1, R11.2
unnamed: C10.2, IC3.11 (VREFOUT), IC3.12 (VREFIN)
unnamed: R14.1, R16.2
unnamed: R7.2, T1.2
unnamed: R13.1, R18.2
unnamed: F4.1, R17.1
unnamed: IC2.13 (X), R5.2
unnamed: F3.2, JP1.4 (2)
unnamed: IC2.3 (Y), R6.2
unnamed: C8.1, C9.1, IC3.10 (VIN-), R6.1
R1: C7.2, C9.2, IC3.9 (VIN+), R5.1
RESET: C14.2, IC3.19 (RESET), R21.2, X1.22 (GPIO25)
SCLK: IC3.5 (SCLK), X1.23 (SPI_SCLK)
SDI: IC3.23 (SDI), X1.19 (SPI_MOSI)
SDO: IC3.6 (SDO), X1.21 (SPI_MISO)
VIN-1: IC2.1 (Y0), IC2.11 (X3), R1.2, T1.4
VIN-2: IC2.4 (Y3), IC2.5 (Y1), R2.2, T2.4
VIN-3: IC2.2 (Y2), R3.2, T3.4
VS-A: IC2.10 (A), X1.7 (GPIO04)
VS-B: IC2.9 (B), X1.10 (RXD)

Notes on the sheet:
AC voltage dividers with isolation transformers
Isolated 5V Power Supply
DC Decoupling Caps
Raspberry Pi Connector
CS5463 Energy meter IC
Voltage Sense Filter
Current Sense Filter
Current board select MUX
Mounting holes
AC1
AC2
AC3
Neutral
Ground

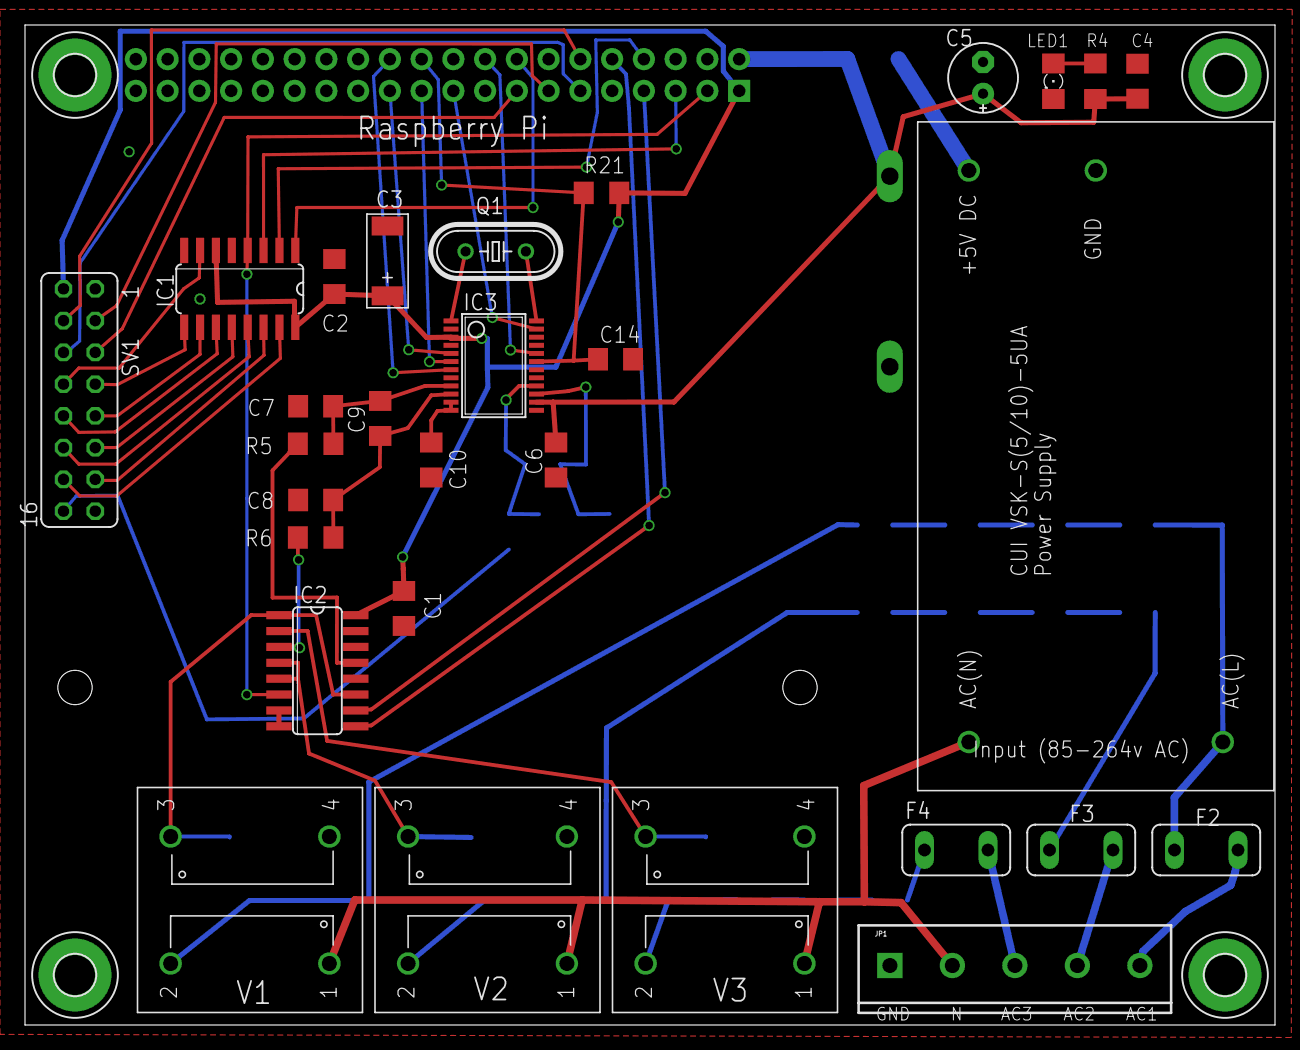
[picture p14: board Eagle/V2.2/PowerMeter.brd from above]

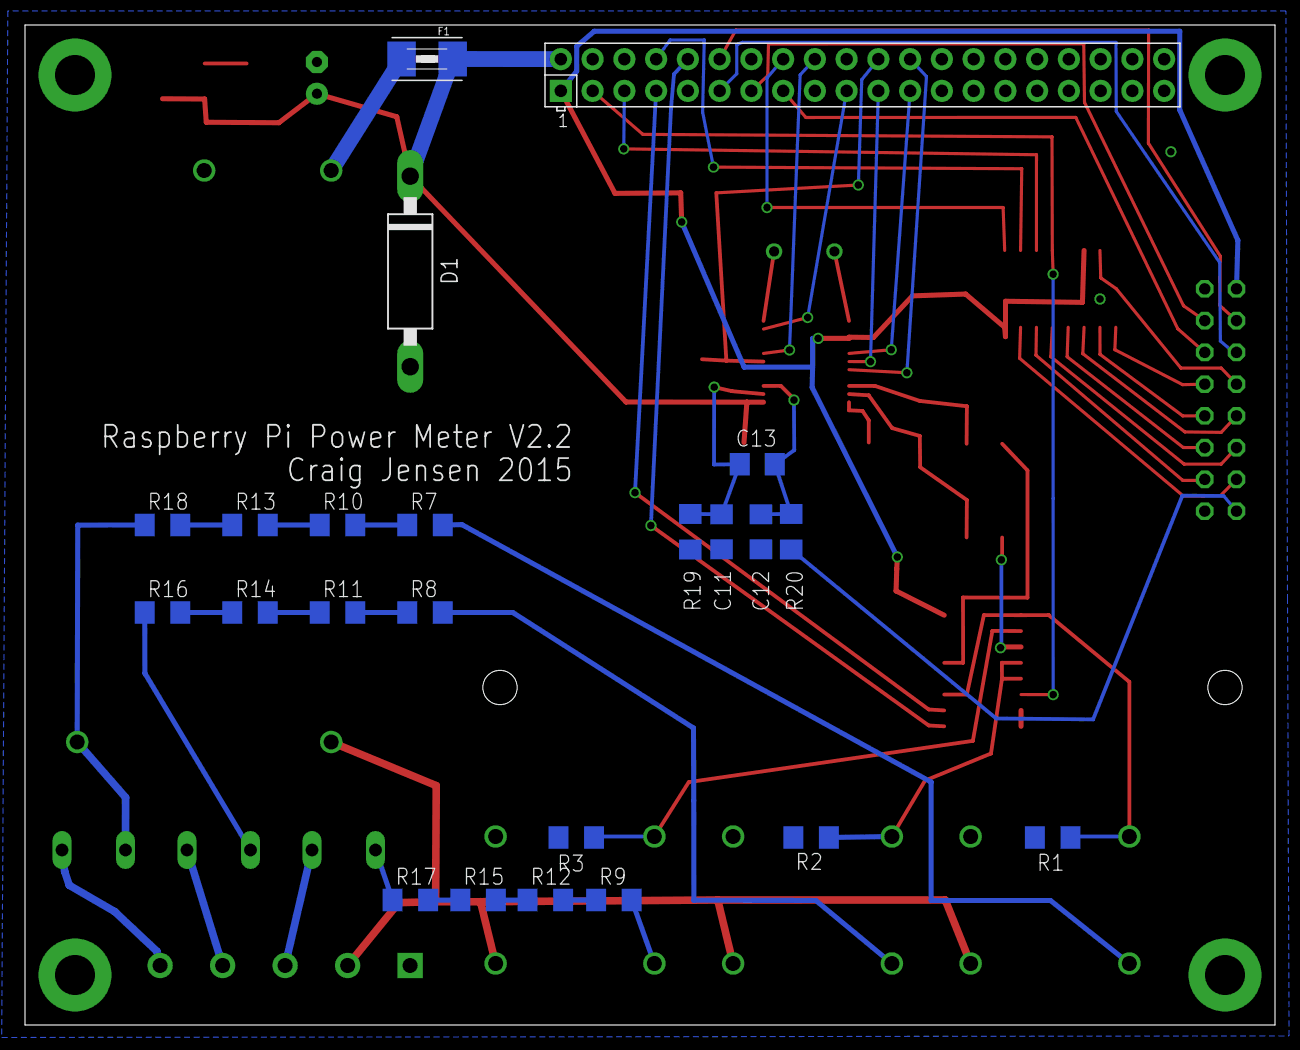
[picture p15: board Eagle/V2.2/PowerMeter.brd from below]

Board: 2 copper layers, 100.0 x 80.0 mm, 56 parts (23 on the bottom side), 61 nets.

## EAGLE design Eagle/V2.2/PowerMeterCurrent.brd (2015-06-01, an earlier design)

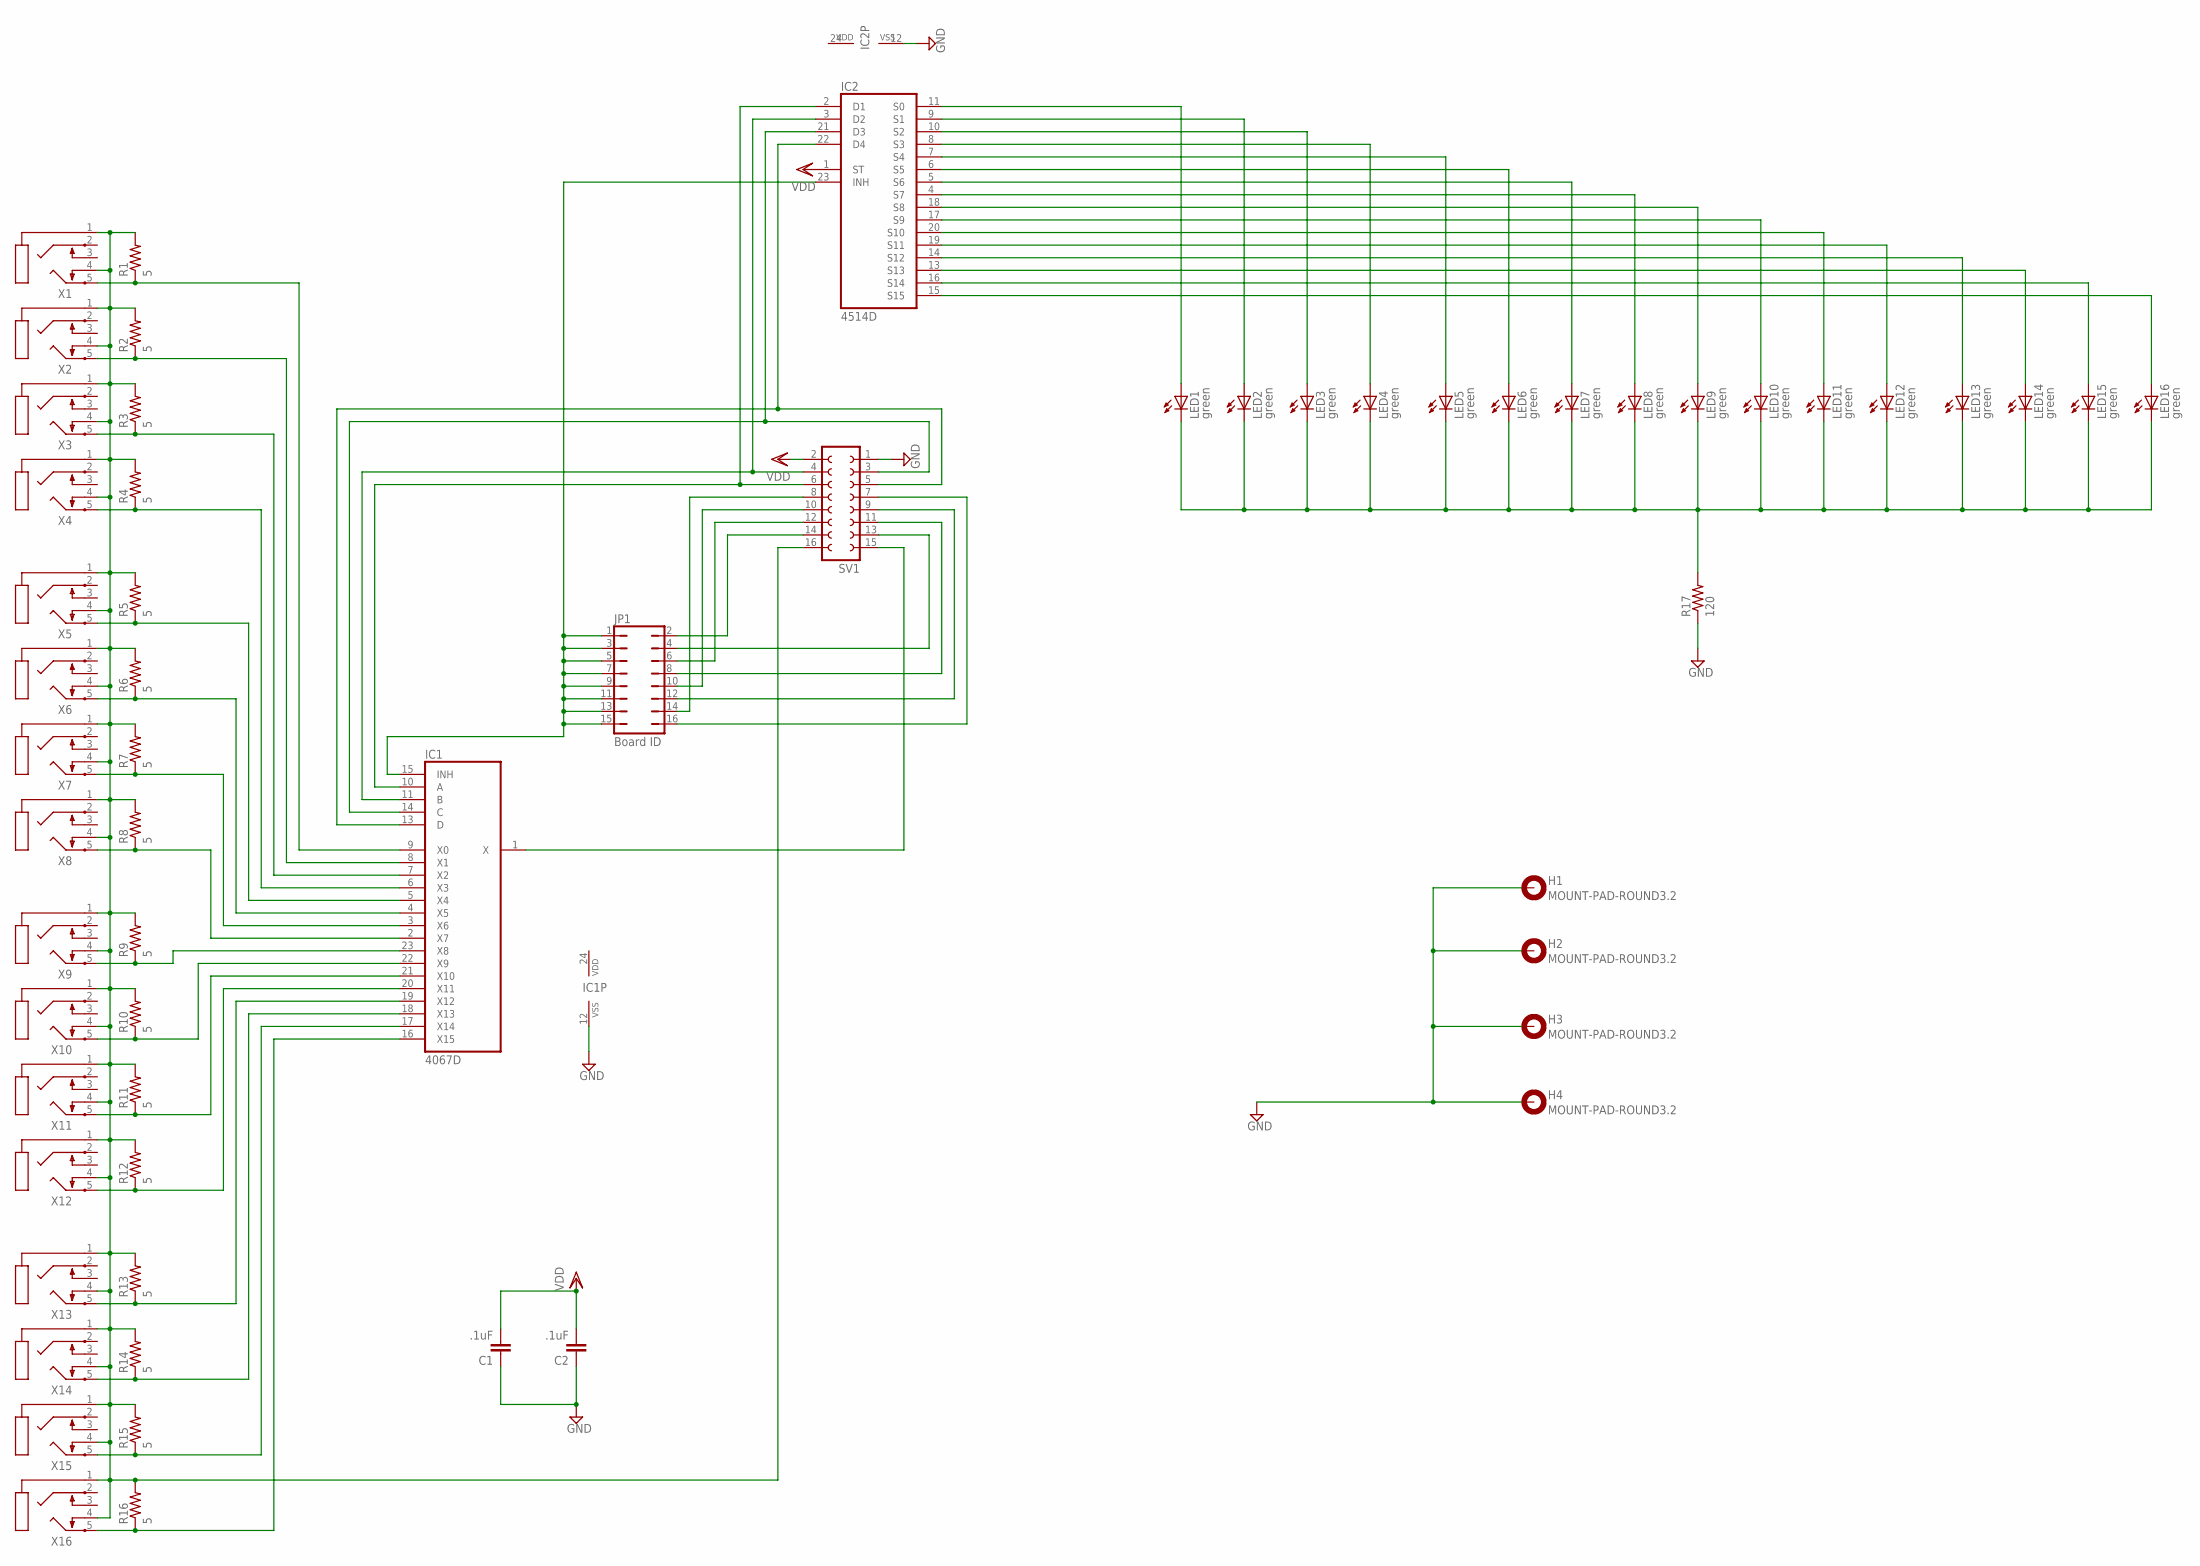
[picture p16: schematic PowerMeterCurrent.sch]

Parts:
C1, C2: .1uF; C1206; PARTNO C1206C104K5RAC7867
H1, H2, H3, H4: MOUNT-PAD-ROUND3.2; 3,2-PAD
IC1: 4067D; SO24W; PARTNO 74HC4067D,652
IC2: 4514D; SO24W; PARTNO 74HC4514D,652
JP1: Board ID; JP8Q; PARTNO 67996-416HLF
LED1, LED2, LED3, LED4, LED5, LED6, LED7, LED8, LED9, LED10, LED11, LED12, LED13, LED14, LED15, LED16: green; LED_1206; PARTNO LTST-C150GKT
R1, R2, R3, R4, R5, R6, R7, R8, R9, R10, R11, R12, R13, R14, R15, R16: 5; R1206; PARTNO RC1206FR-075R1L
R17: 120; R1206; PARTNO RC1206FR-07120RL
SV1: FE08-2; PARTNO SSQ-108-02-T-D
X1, X2, X3, X4, X5, X6, X7, X8, X9, X10, X11, X12, X13, X14, X15, X16: STEREOJACK; STX3100; PARTNO SJ1-3525N

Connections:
GND: C1.1, C2.1, H1.B3,2, H2.B3,2, H3.B3,2, H4.B3,2, IC1.12 (VSS), IC2.12 (VSS), R17.1, SV1.1
unnamed: IC1.10 (A), IC2.2 (D1), SV1.6
unnamed: IC2.15 (S15), LED16.A
unnamed: IC1.11 (B), IC2.3 (D2), SV1.4
unnamed: IC1.14 (C), IC2.21 (D3), SV1.3
unnamed: IC1.13 (D), IC2.22 (D4), SV1.5
unnamed: IC1.15 (INH), IC2.23 (INH), JP1.1, JP1.3, JP1.5, JP1.7, JP1.9, JP1.11, JP1.13, JP1.15
unnamed: JP1.14, SV1.8
unnamed: JP1.10, SV1.10
unnamed: IC2.16 (S14), LED15.A
unnamed: JP1.6, SV1.12
unnamed: JP1.2, SV1.14
unnamed: R1.2, R2.2, R3.2, R4.2, R5.2, R6.2, R7.2, R8.2, R9.2, R10.2, R11.2, R12.2, R13.2, R14.2, R15.2, R16.2, SV1.16, X1.1, X1.4, X2.1, X2.4, X3.1, X3.4, X4.1, X4.4, X5.1, X5.4, X6.1, X6.4, X7.1, X7.4, X8.1, X8.4, X9.1, X9.4, X10.1, X10.4, X11.1, X11.4, X12.1, X12.4, X13.1, X13.4, X14.1, X14.4, X15.1, X15.4, X16.1, X16.4
unnamed: JP1.4, SV1.13
unnamed: JP1.8, SV1.11
unnamed: JP1.12, SV1.9
unnamed: JP1.16, SV1.7
unnamed: IC1.1 (X), SV1.15
unnamed: IC1.5 (X4), R5.1, X5.5
unnamed: IC2.13 (S13), LED14.A
unnamed: IC1.9 (X0), R1.1, X1.5
unnamed: LED1.C, LED2.C, LED3.C, LED4.C, LED5.C, LED6.C, LED7.C, LED8.C, LED9.C, LED10.C, LED11.C, LED12.C, LED13.C, LED14.C, LED15.C, LED16.C, R17.2
unnamed: IC1.8 (X1), R2.1, X2.5
unnamed: IC1.7 (X2), R3.1, X3.5
unnamed: IC1.6 (X3), R4.1, X4.5
unnamed: IC1.4 (X5), R6.1, X6.5
unnamed: IC1.3 (X6), R7.1, X7.5
unnamed: IC1.2 (X7), R8.1, X8.5
unnamed: IC1.23 (X8), R9.1, X9.5
unnamed: IC2.14 (S12), LED13.A
unnamed: IC2.19 (S11), LED12.A
unnamed: IC2.20 (S10), LED11.A
unnamed: IC2.17 (S9), LED10.A
unnamed: IC2.18 (S8), LED9.A
unnamed: IC2.4 (S7), LED8.A
unnamed: IC2.5 (S6), LED7.A
unnamed: IC2.6 (S5), LED6.A
unnamed: IC2.7 (S4), LED5.A
unnamed: IC2.8 (S3), LED4.A
unnamed: IC1.22 (X9), R10.1, X10.5
unnamed: IC1.21 (X10), R11.1, X11.5
unnamed: IC2.10 (S2), LED3.A
unnamed: IC2.9 (S1), LED2.A
unnamed: IC2.11 (S0), LED1.A
unnamed: IC1.20 (X11), R12.1, X12.5
unnamed: IC1.18 (X13), R14.1, X14.5
unnamed: IC1.17 (X14), R15.1, X15.5
unnamed: IC1.19 (X12), R13.1, X13.5
unnamed: IC1.16 (X15), R16.1, X16.5
VDD: C1.2, C2.2, IC1.24 (VDD), IC2.1 (ST), IC2.24 (VDD), SV1.2

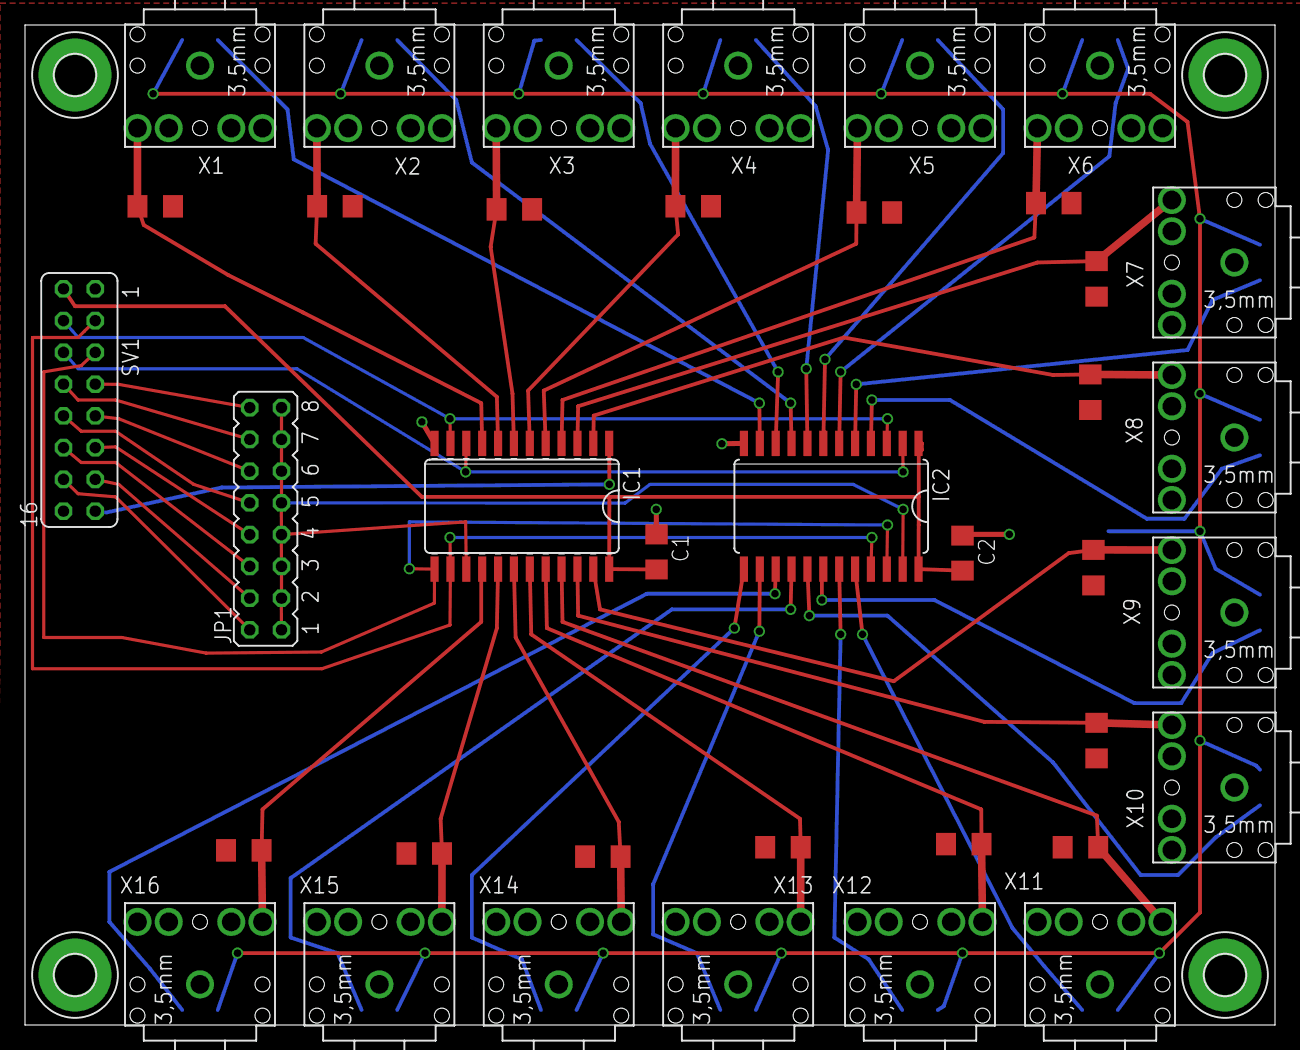
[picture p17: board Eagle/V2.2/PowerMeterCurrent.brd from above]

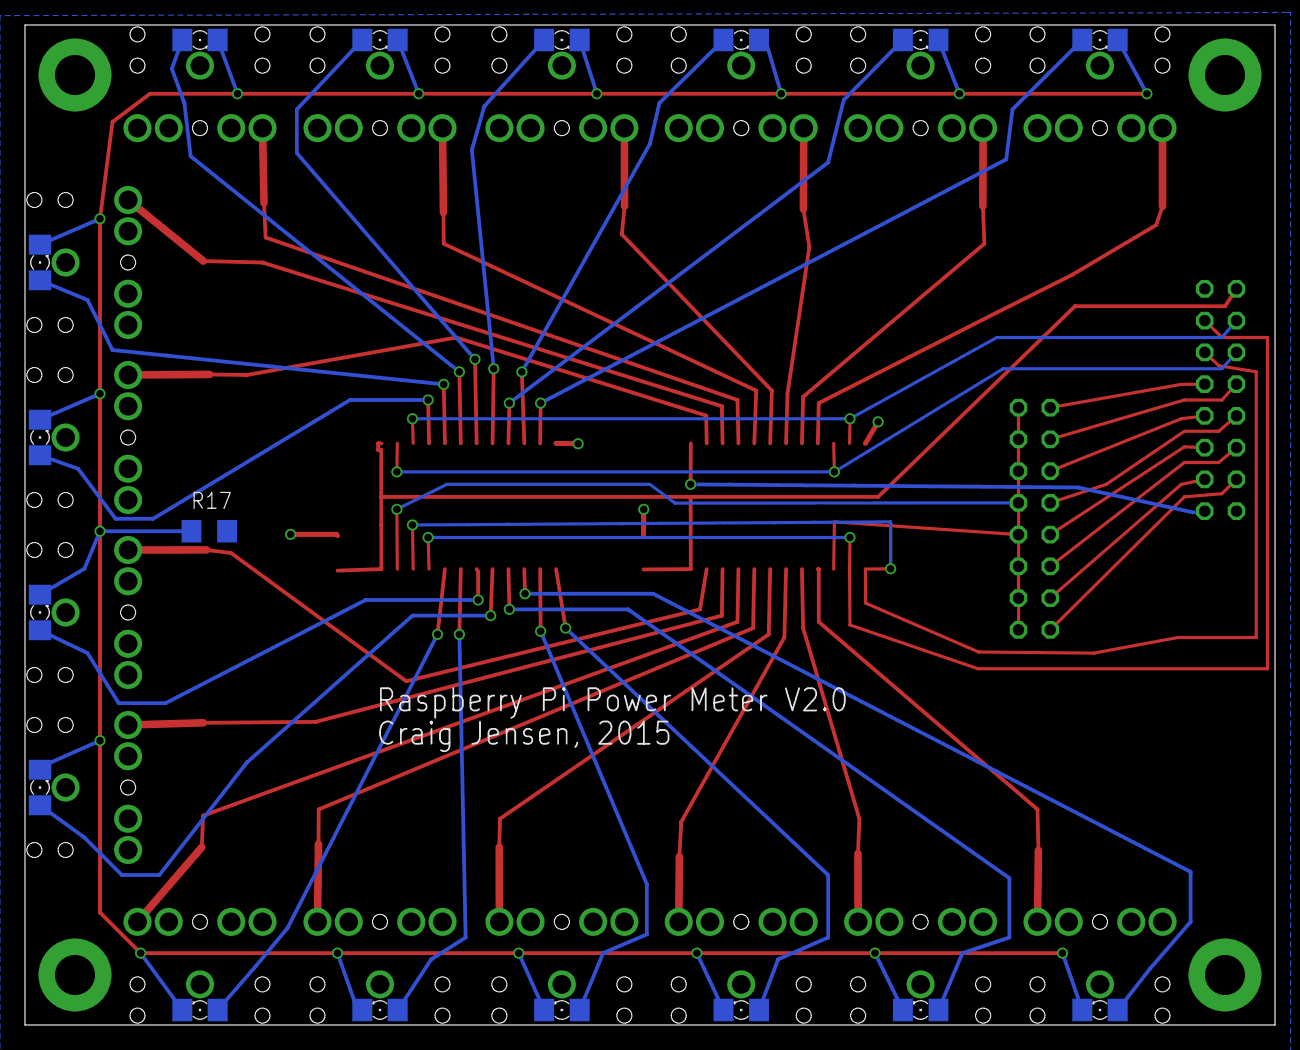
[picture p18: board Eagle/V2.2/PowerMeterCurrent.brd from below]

Board: 2 copper layers, 100.0 x 80.0 mm, 59 parts (17 on the bottom side), 50 nets.

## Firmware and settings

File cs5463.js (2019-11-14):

var cs5463 = null;
// comment below line for WebMatrix testing
var cs5463 = require("cs5463");
require("./common");

var samples = 500;   // number of instantaneous voltage and current samples to collect for each measurement
var bytesPerSample = 10;
var sampleBuffer = Buffer.alloc(samples * bytesPerSample);
var Mode = "000061";  // Enable hpf on current and voltage channels
var Config = "001001"; // set interrupt High-Low
var _DeviceOpen = false;
var Configuration = null;
var CalculatedFrequencies = [];

var InputPins = {
    isr: 18         // Header 18 - GPIO5  (interrupt pin - connect to INT (20) on CS5463)
};

var OutputPins = {
    channel0: 11,    // header 11 - GPIO0
    channel1: 12,    // header 12 - GPIO1
    channel2: 13,    // header 13 - GPIO2
    channel3: 15,    // header 15 - GPIO3
    board0: 16,      // header 16 - GPIO4
    board1: 8,      // header 8 - TxD
    board2: 5,      // header 5 - GPIO9
    voltage0: 7,    // header 7  - GPIO7
    voltage1: 10,    // header 10  - RxD
    disable: 3,     // header 3  - SDA0   (8 and 9 have internal pull-up resistors, use 15, 16 if that causes a problem)
    reset: 22        // header 22  - GPIO6
};

var Registers = {
    Config: 0,
    CurrentDCOffset: 1,
    CurrentGain: 2,
    VoltageDCOffset: 3,
    VoltageGain: 4,
    CycleCount: 5,
    PulseRateE: 6,
    InstCurrent: 7,
    InstVoltage: 8,
    InstPower: 9,
    RealPower: 10,
    RmsCurrent: 11,
    RmsVoltage: 12,
    Epsilon: 13, // line frequency ratio
    PowerOffset: 14,
    Status: 15,
    CurrentACOffset: 16,
    VoltageACOffset: 17,
    Mode: 18,
    Temp: 19,
    AveReactivePower: 20,
    InstReactivePower: 21,
    PeakCurrent: 22,
    PeakVoltge: 23,
    ReactivePowerTriangle: 24,
    PowerFactor: 25,
    InterruptMask: 26,
    ApparentPower: 27,
    Control: 28,
    HarmonicActivePower: 29,
    FundamentalActivePower: 30,
    FundamentalReactivePower: 31
};

var GetCycleCount = function () {
    if (Configuration == null)
        return 4000; // default to 4000 (1sec)

    var tmp = Configuration.SampleTime * 4000;
    if (tmp < 100)
        return 100; // CS5490 docs say not to use < 100
    if (tmp > 4000 * 60 * 5)
        return 4000 * 60 * 5; // 5 min seems long enough
    return tmp;
}

var sleep = function (delayMs) {
    var s = new Date().getTime();
    while ((new Date().getTime() - s) < delayMs) {
        //do nothing
        //console.log('sleeping');
    }
}

var write = function (cmd, desc) {
    if (_DeviceOpen) {
        cs5463.send(cmd);
        if (desc != null)
            console.log('write: ' + desc + '(' + cmd + ')')
    }
}

var writeRegister = function (register, data, desc) {
    if (_DeviceOpen) {
        while (data.length < 6)
            data = '0' + data;
        while (register.length < 2)
            register = '0' + register;
        var cmd = (0x40 + (register << 1)).toString(16) + data
        write(cmd, desc);
    }
}

var read = function (register, desc) {
    if (_DeviceOpen) {
        var cmd = (register << 1).toString(16) + 'FFFFFF';
        while (cmd.length < 8)
            cmd = '0' + cmd;

        var result = cs5463.send(cmd);

        //console.log('cmd: ' + cmd + ' -> ' + result)

        var ret = Buffer.from(result, 'hex').slice(1);

        if (desc != null)
            console.log('read: ' + desc + '(' + cmd + ') -> ' + ret.toString('hex')); // + '  ' + result);

        return ret;
    } else {
        return null;
    }

}

var getCommand = function (register) {
    var c = (register << 1).toString(16);
    if (c.length == 1)
        c = '0' + c;
    return c + 'FFFFFF';
}

var makeReadCommand = function (registers) {
    var cmd = "";
    if (registers instanceof Array) {
        for (var i = 0; i < registers.length; i++) {
            cmd += getCommand(registers[i]);
        }
    } else {
        cmd = getCommand(registers);
    }

    return cmd;
}

function buf2hex(buffer) { // buffer is an ArrayBuffer
    return Array.prototype.map.call(new Uint8Array(buffer), x => ('00' + x.toString(16)).slice(-2)).join('');
}

var Encode2sComplememt = function (val, binPt, neg) {
    if (neg && val < 0)
        return (Math.round((val + Math.pow(2, binPt + 1)) * Math.pow(2, 23 - binPt)) | 0x800000).toString(16);
    return Math.round(val * Math.pow(2, 23 - binPt)).toString(16);
}

var Decode2sComplement = function (buffer, binPt, neg) {
    var n = parseInt(buf2hex(buffer), 16);
    var val = n / Math.pow(2, 23 - binPt);
    if (neg && buffer[0] & 0x80)
        return -1 * (Math.pow(2, binPt + 1) - val);
    return val;
}

var resultFromBuffer = function (buffer, index) {
    var offset = index * 4 + 1;
    return buffer.slice(offset, offset + 3);
}

var ResetIfNeeded = function () {

    var epsilon = read(Registers.Epsilon);
    var mode = read(Registers.Mode);
    var config = read(Registers.Config);
    var status = read(Registers.Status);
    var cycleCount = read(Registers.CycleCount);

    // Check status of:
    //   IOR and VOR
    //   IROR, VROR, EOR, IFAULT, VSAG
    //   TOD, VOD, IOD, LSD 
    if ((status[0] & 0x03) || (status[1] & 0x7C) || (status[2] & 0x58)) {
        console.log('Resetting due to incorrect status: ' + status.toString('hex'));
        console.error('Resetting due to incorrect status: ' + status.toString('hex'));
        Reset();
    }

    else if (mode.toString('hex') != Mode) {
        console.log('Resetting due to incorrect Mode: ' + mode.toString('hex') + ' expected: ' + Mode);
        Reset();
    }
    else if (config.toString('hex') != Config) {
        console.log('Resetting due to incorrect Config: ' + config.toString('hex') + ' expected: ' + Config);
        Reset();
    }
    else if (parseInt('0x' + cycleCount.toString('hex')) != GetCycleCount()) {
        console.log('Resetting due to incorrect CycleCount: ' + parseInt('0x' + cycleCount.toString('hex')) + ' expected: ' + GetCycleCount());
        Reset();
    }
    else {
        //Reset();
        //console.log('Reset not needed:' + epsilon.toString('hex') + " " + mode.toString('hex') + " " + config.toString('hex'));
    }
}

var DumpRegisters = function () {
    console.log("Register dump:");
    for (var propertyName in Registers) {
        var val = Registers[propertyName];
        //vconsole.log(val + ' - ' + propertyName + ': ' + read(val).toString('hex'));
        console.log(val + ' - ' + propertyName + ': ' + read(val).toString('hex'));
    }
}
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

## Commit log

2015-02-18 plot all probes on waveform graph
2015-02-18 Add probe details for realtime view
2015-03-05 removed total from circuits when only 1 probe
2015-03-20 add ability to set groupby in circuit view
2015-05-04 Add Eagle files
    [PowerMeter.brd, PowerMeter.sch, PowerMeterCurrent.brd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]
2015-06-01 Updated Eagle files
    [PowerMeter.brd, PowerMeter.sch, PowerMeterCurrent.brd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]
2015-06-03 Fixed BOM for current board
    [PowerMeterCurrent.sch]
2015-06-10 Added V2.2 Eagle files and removed old versions due to hardware bug
    [PowerMeter.brd, PowerMeter.sch, PowerMeterCurrent.brd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]
2015-06-17 Support of three voltage channels
2015-06-24 Improve perf of config update and fix crash when deleting circuits
2015-07-07 Fixed crash when adding new circuit
2015-09-09 fixed case on ReadState
2015-10-13 overload toFixed to fix rounding
    [cs5463.js]
2015-10-13 Replace toFixed with new round function
    [cs5463.js]
2015-11-07 Update default voltage scale factor
2015-11-12 Switch over to jquery globalization
2015-11-13 filter out default
2015-12-10 update scale factors for current probes
2015-12-18 change scale factor for 30A probe
2016-01-03 log sample time
2016-09-06 Add probe type
    0 = load only, 1 = source only, 2 = both
2016-09-07 fix probe insert query
2016-09-19 zero current for sourcetypes 1 and 2
2017-12-14 Updated default sensors
2019-01-07 install spi
2019-01-07 add spi and uart setup
2019-01-07 fix spi
2019-01-09 out pin fix
2019-01-19 change pin mode
2019-01-21 improve board detection
2019-01-29 Support additional voltage channels
2019-10-05 add v4.0 eagle files
    [PowerMeter.brd, PowerMeter.sch, PowerMeterCurrent.brd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]
2019-10-30 fix current scale
2019-11-07 add samplecount
2019-11-07 remove samplecount
2019-11-07 fix samplecount
2019-11-08 Add SampleTime
2019-11-09 harden sample time
2019-11-12 fix main page device name

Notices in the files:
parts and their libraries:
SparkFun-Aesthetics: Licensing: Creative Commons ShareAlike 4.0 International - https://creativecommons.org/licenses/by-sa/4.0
